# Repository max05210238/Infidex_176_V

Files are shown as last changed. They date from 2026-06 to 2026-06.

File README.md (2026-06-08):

# Infidex 176 V

Open source 3D printed panoramic 35mm film camera. Shoots a 3:1 panoramic frame (72 x 24 mm) on standard 35mm film using a Mamiya TLR taking lens.

Designed by **Denis Aminev** (Time to Waste). This repository is a community mirror created to preserve the project after the original site goes offline. See [Source and license](#source-and-license).

---

## Download

**Want everything in one file?** Download [`Infidex_176_V_complete.zip`](downloads/Infidex_176_V_complete.zip) (~20 MB) — this is the author's original release archive containing all STL, FBX, MOD files, the PDF manual, and the 3ds Max source. Just unzip and print.

You can also clone the full repo:

```bash
git clone https://github.com/max05210238/Infidex_176_V.git
```

Or use GitHub's **Code > Download ZIP** button above to grab the entire repository (docs included).

---

## What this is

Infidex 176 V is a fully working camera you print on an FFF/FDM printer and finish by hand. It is a plastic camera, so tolerances depend heavily on your printer, filament, and finishing. Expect to iterate. The designer printed all his cameras on a stock Ender 3 (Marlin firmware, Linear Advance) in cheap ABS.

| Spec | Value |
|---|---|
| Format | 3:1 panoramic, 72 x 24 mm |
| Film | 35mm (135) |
| Frames per 36-exp roll | 18 (19 if loaded in full dark, no leader waste) |
| Sprockets per frame | 16 (two standard 3:2 frames wide) |
| Taking lens | Mamiya TLR (C2/22/220, C3/33/330). 80mm recommended |
| Equivalent focal length | ~35mm on the 72mm-wide panoramic frame |
| Infinity focus (Mamiya 80mm) | ~31 m (~102 ft), helicoid fully screwed in |
| Focus throw | ~300 deg from infinity to 2 m |
| Body length | 168 mm |
| Body height (unibody) | 67 mm |
| Body thickness | 37.8 mm |
| Filament per camera | < 600 g (22 oz) |
| Tripod mount | 1/4" brass insert in base (8 x 8 mm) |

---

## Repository contents

```
Infidex_176_V/
├── Infidex 176 V manual.pdf         Original PDF manual by Denis Aminev
├── Infidex 176 V_NEWEST.max         3ds Max master CAD source file
├── STL/                              Print-ready STL parts
│   ├── Body/                           Body shells, unibody, doors (10 files)
│   ├── Lens mount/
│   │   ├── Focusing Helicoid/          Helicoid parts inc. Blue Dot variants (15 files)
│   │   ├── Classic Cone/               Fixed cone mount (3 files)
│   │   ├── Tube/                       Tube mount (3 files)
│   │   └── Old Version cone for T-22 lens/  Legacy T-22 cone (4 files)
│   └── Small parts/                    Knobs, gears, viewfinders, lens hoods, etc. (25 files)
├── FBX/                              FBX mesh exports (62 files)
├── MODS/                             Community modifications
│   ├── stl/                            Modified body, doors, helicoid mount (7 files)
│   └── fbx/                            FBX versions of the mods (7 files)
├── downloads/
│   └── Infidex_176_V_complete.zip    Author's original release archive (~20 MB)
├── docs/
│   ├── PRINTING.md                   Part catalog, print settings, dimensions
│   ├── ASSEMBLY.md                   Step-by-step build (14 steps)
│   ├── FOCUSING_AND_USAGE.md         Focus calibration, DOF table, shooting, scanning
│   └── VIDEO_TRANSCRIPT.md           Transcript of the designer's build video
├── NOTICE.md                         Attribution and redistribution notice
└── README.md                         This file
```

> If you regenerate STLs from `Infidex 176 V_NEWEST.max`, keep the part names above so the assembly docs stay valid.

---

## Required materials and tools

| Item | Notes |
|---|---|
| Mamiya TLR taking lens | C2/22/220 or C3/33/330. 80mm is the recommended focal length |
| Filament, 1 roll | Whole camera is under 600 g. ABS, PLA, or PETG all work (see notes below) |
| Superglue | Two-component with activator preferred. Standard CA works |
| Rigid wire, 0.6 to 0.8 mm | 20 to 30 cm. Stainless steel. Must spring well |
| Black flocked self-adhesive paper or matte black vinyl | Light-trap and anti-reflection surfaces |
| Black foam (dark gray minimum) | Light seals and film tension shims |
| Double sided tape | Not foam based |
| Wire nippers | |
| Calipers, metric | For dimension checks |
| Sandpaper, 100P to 800P | Grit depends on your filament |
| Spanner wrench | For the Mamiya lens mount nut |
| Scissors, tweezers | |
| Safety goggles + respirator | Mandatory for ABS fumes and superglue |

### Optional

35mm optical viewfinder, cutting knife with replaceable blades, 3D-print bed adhesive (spray), epoxy, plastic putty, 1000P fine sandpaper, textured bumper paint (e.g. Mipa), brass heat inserts (1/4" 8x8 mm and M3 4.5x6 mm), four or more M3x10 screws, soldering iron.

### Filament notes

ABS is the designer's choice: cheap, easy to shape by hand, good mechanical properties, but it shrinks, needs bed adhesive, slow speeds (30 to 70 mm/s), and an enclosed chamber. PLA works fine (tested by a friend of the designer). PETG can be too flexible in some parts. Composite filaments hide print lines well but are expensive and not every printer handles them.

---

## Print settings (designer's ABS profile)

| Setting | Value |
|---|---|
| Nozzle | 0.4 mm |
| Layer height | 0.2 mm |
| First layer height | 0.23 mm (glass bed) |
| Inner perimeters | 4 (important for rigidity) |
| Min top/bottom thickness | 2 mm |
| Infill | 25% max |
| Bed | 4 mm polished glass (PEI also fine) |

Print order does not matter, but print the **body first** to verify dimensions and tolerance before committing the rest. Reasonable deviation of 0.2 to 0.4 mm on printed parts is fine. See [docs/PRINTING.md](docs/PRINTING.md) for the full part catalog and per-part orientation.

---

## Build at a glance

Full walkthrough in [docs/ASSEMBLY.md](docs/ASSEMBLY.md).

1. Check body dimensions (37.8 mm thickness, 36.03 mm reference height).
2. Glue or screw the lens mount to the body. Install brass inserts if used.
3. Build the lens mount: lens board to inner thread, snap fixation ring, glue focus ring to the fixation ring (not the mount), verify the thread screws all the way in.
4. Install spool base, taking spool shaft, sprockets gear and sprocket shaft.
5. Bend the V-spring from wire, install it and the rewind knob.
6. Hinge the door with a ~63 mm wire pin. Line the pressure plate with black flock and add 4 to 5 mm foam tension strips.
7. Cold shoe, optional cable release port and lever knob, optional lens hood.
8. Calibrate the focus marks against ground glass (see [docs/FOCUSING_AND_USAGE.md](docs/FOCUSING_AND_USAGE.md)).

Wear eye and respiratory protection throughout. Glue fumes will make your eyes water.

---

## Lens mount options

Print only one set:

- **Focusing helicoid** (recommended, allows real focusing)
- **Classical cone** (fixed)
- **Tube mount** (fixed)

The lens cone from the previous IV model is compatible. All three are available with M3 screw holes.

**Blue Dot lens owners:** Blue Dot copies of the 80mm have a different flange distance and will not reach infinity with the standard helicoid. Print the shorter parts instead: `Helicoid_INNER_ring_80mm_shorter-2mm.STL` and `Helicoid_FOCUS_ring_ribs_shorter-2mm.STL`.

---

## Flocking paper templates

| Size | Location |
|---|---|
| 73 x 23 mm | Top and bottom of film chamber |
| 43 x 23 mm | Sides of film chamber |
| 82 x 33 mm | Pressure plate |

---

## Known limitations

- The frame counter requires **2 revolutions per shot** with the stock 8-tooth sprocket gear. A 16-tooth gear fixes this but lengthens the body.
- Long panoramic negatives are hard to scan at a normal lab. The designer scans on an Epson V850 Pro, or DSLR-scans and stitches two frames.

---

## Credits

Project by **Denis Aminev**, Time to Waste.

- **PaperBen** and **Giuseppe Spataro** for testing, advice, and inspiration. Giuseppe also solved the Blue Dot infinity issue.
- **ballanux** (YouTube) for helicoid system inspiration.
- **Oscar Oweson**, creator of the Oxygen panoramic camera (panomicron.com), for inspiration on some parts.
- **GLOwl** for the printable lens cap that inspired the kit version.
- **@analog_astronaut** for boosting the project.

---

## File sources

All design files in this repository originate from Denis Aminev's official releases on [timetowaste.ru](https://timetowaste.ru). The files were downloaded directly from the author's site before the scheduled shutdown.

| Path | Source | Notes |
|---|---|---|
| `Infidex 176 V manual.pdf` | Author's site, unchanged | The original PDF assembly and printing guide |
| `Infidex 176 V_NEWEST.max` | Author's site, unchanged | 3ds Max master CAD — regenerate STLs from this |
| `STL/` | Author's site, unchanged | Print-ready parts exported by the author |
| `FBX/` | Author's site, unchanged | Mesh exports for viewing/editing in other 3D tools |
| `MODS/` | Author's site, unchanged | Community-contributed body and door variants |
| `downloads/Infidex_176_V_complete.zip` | Author's original release archive | All binary files in one download (~20 MB) |
| `docs/` | Written for this mirror | English documentation reorganized from the PDF manual and the author's build video for easier web reading |

No design files have been modified. The documentation in `docs/` is a reorganization of the author's own content into Markdown for web readability.

---

## Source and license

Original project, files, and documentation by Denis Aminev (Time to Waste).

The designer's original site is shutting down. His own words:

> This website will disappear on 21 March 2027. Project brought to a point where I am satisfied with the results and I will no longer pay for this domain. Feel free to distribute files of the project on any other website or a platform. Thank you. Peace.

This repository exists to keep the project available after that date. All design credit stays with Denis Aminev. If you redistribute further, keep this attribution intact. See [NOTICE.md](NOTICE.md).

Original joint image gallery: https://timetowaste.ru/joint

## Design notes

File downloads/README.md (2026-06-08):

# Downloads

## Infidex_176_V_complete.zip (~20 MB)

The author's original release archive containing all project files in one download:

- All STL print files (organized by category)
- All FBX mesh exports
- Community modifications (MODS)
- Original PDF manual
- 3ds Max source file (.max)

This is the same set of files distributed across the repository, bundled for convenience. The archive was downloaded directly from [timetowaste.ru](https://timetowaste.ru) before the site's scheduled shutdown.

To download, click the file above then use the **Download raw file** button, or clone the repository.

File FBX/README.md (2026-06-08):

# FBX — Mesh Exports

61 files (mostly FBX, plus a few STL and DAE for metal parts). These are the author's mesh exports for viewing and editing in 3D applications other than 3ds Max.

The FBX files mirror the STL set but in a flat directory. For printing, use the STL files instead. The Kodak cone files (`Kodak_cone_base.*`, `Kodak_lens_board.*`) and metal part references (`METAL-Counter_gear.dae`, `METAL-Sprocket_gear.dae`, `METAL-Sprocket_shaft.dae`) are only available here.

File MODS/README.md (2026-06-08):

# MODS — Community Modifications

14 files (7 STL + 7 FBX) — community-contributed variants of the body, doors, and helicoid mount.

| Part | Description |
|---|---|
| `Body_top` / `Body_bottom` | Modified body shells |
| `Door_v1` through `Door_v4` | Four alternate door designs |
| `Helicoid_MOUNT_BASE` | Modified helicoid mount base |

Both STL (for printing) and FBX (for editing) versions are provided in their respective subfolders.

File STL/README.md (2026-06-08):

# STL — Print-Ready Parts

57 STL files organized by function. All files are the author's original exports from `Infidex 176 V_NEWEST.max`.

## Folders

| Folder | Contents |
|---|---|
| `Body/` | Body shells (top/bottom, unibody, ver2 variants) and four door options |
| `Lens mount/Focusing Helicoid/` | Recommended mount — allows real focusing. Includes Blue Dot shorter variants |
| `Lens mount/Classic Cone/` | Fixed-focus cone mount |
| `Lens mount/Tube/` | Fixed-focus tube mount |
| `Lens mount/Old Version cone for T-22 lens/` | Legacy cone for Lomo T-22 lens (from earlier model) |
| `Small parts/` | Knobs, gears, viewfinders, lens hoods, lens cap, cold shoe, pressure plate, etc. |

Print only **one** body set (top+bottom or unibody), **one** lens mount type, and **one** door variant. See [docs/PRINTING.md](../docs/PRINTING.md) for settings and orientation.

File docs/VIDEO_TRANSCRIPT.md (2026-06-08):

# Build Video Transcript

Transcript of Denis Aminev's Infidex IV-to-V build video, organized by chapter with timestamps. Lightly cleaned for readability; the designer narrated it as improvised live commentary. Read the PDF manual for everything not covered here.

---

## 1. Intro (0:21)

Assembling the new Infidex V camera. This one is full improvisation, not scripted like the earlier videos. Plan: disassemble an Infidex IV and reuse its optical viewfinder and Mamiya 80mm lens.

## 2. Materials and tools (1:06)

Walks through the essential materials and tools laid out, plus a second table of "non-essential" items. Foam is essential. Open the assembly guide first. Calipers, mislabeled as not essential, are needed.

## 3. Checking dimensions (1:34)

- Whole camera thickness should be 37.8 mm, measured mid-side. Measured: 37.51 mm. Acceptable for FFF/FDM.
- Model height should be 36.03 mm. Measured: ~36 mm. Good to proceed.

## 4. Body assembly (2:17)

Check part fitment. A small gap between halves is fine. Chisel off bumps and flatten with sandpaper, scraping carefully (sharp edges). Check the smaller parts fit too; remove a few bumps where needed.

The taking spool shaft (step 6 in the manual) goes in at an angle first, then upright, then pushed up. Place the shaft holder inside before gluing. File any stiffness until smooth.

There is a pocket at the top right for a gear; it should sit and rotate freely. The sprocket shaft is placed from the top and located in its slot.

Before gluing, place the printed pressure plate on its position as a guide. It moves freely, that is fine. It ensures the two film rails stay flat and parallel while the body halves are glued, which is critical. Do not rush. Press the glued halves together for a few seconds.

A small bump indicates the bottom side of the helicoid mount.

## 5. Helicoid assembly (5:54)

Prepare surfaces and check fit. The thread should screw in and out freely. Snap the fixation ring into its groove so it rotates freely.

Glue the focus ring to the snapped fixation ring, not to the mount, body, or your fingers. Do not apply glue to the focus ring itself, or pushing it on will bond it to the helicoid mount. Apply a decent but mild amount of superglue to the fixation ring.

The mount has two slide guides for the inner-ring rails. Engage them, then rotate clockwise to thread it in.

Only the thread holds the assembly together, so be careful when focusing close. The camera can do mild macro, but unscrewing too far drops the lens out.

Glue the inner thread to the lens board, aligning the matching marks on both parts. Press mildly.

## 6. Door installation (9:12)

The door will not fit at first. Remove material from the hinge points and edges. The lower ledge was printed with supports and ends up slightly thick, so remove a little material until the door fits.

## 7. Brass thread inserts (10:14)

The soldering iron is hot, be careful. Apply heat slowly to seat the inserts. One M3 insert done. The larger 1/4" thread hole is easier to seat than the small M3 ones.

## 8. Spring and hinge wires (11:13)

The hinge uses rigid stainless wire, about 0.62 mm, that goes straight in.

The spring seats inside the body and acts as a stopper for the rewind knob. Form it by making one coil around something thin (an M3 screw, or better a plain nail). Push the coil into place with a file. When seated correctly, pulling the knob shows the spring working as a stopper. This part is hard. ("I cried only three times.")

The winding knob and counter go on after the paint job.

## 9. Pressure plate (12:54)

Line the pressure plate with black flocked paper. It must be black, not light gray or white, or images get halation everywhere. Cut to size and glue on. Matte black vinyl also works; do not use glossy. Apply self-adhesive flocking inside the chamber too. This is easier before the body halves are glued. The cold shoe was installed off-camera.

## 10. Lens installation (13:56)

When transferring the long thread from the disassembled Infidex IV, it may not fit at first; work it until it seats.

## 11. Marking distances on the helicoid (14:44)

Focus on a target at a known distance and mark the helicoid.

- 2 m mark made by focusing on a target exactly 2 m away.
- Then 5 m, 10 m, 15 m, 20 m, and 31 m to infinity.

Camera is then painted and fully functional.

## 12. A little talk (15:52)

There was a small light leak in the lens board. It was found and fixed in the STL files (link in the original video description). Read the assembly guide first; a lot is not covered in the video.

## 13 to 15. Test shots and outro (16:11)

Test images shown. Thanks to viewers. Plus a t-shirt a friend gifted.

---

Original channel and site: Time to Waste (timetowaste.ru). Project by Denis Aminev.

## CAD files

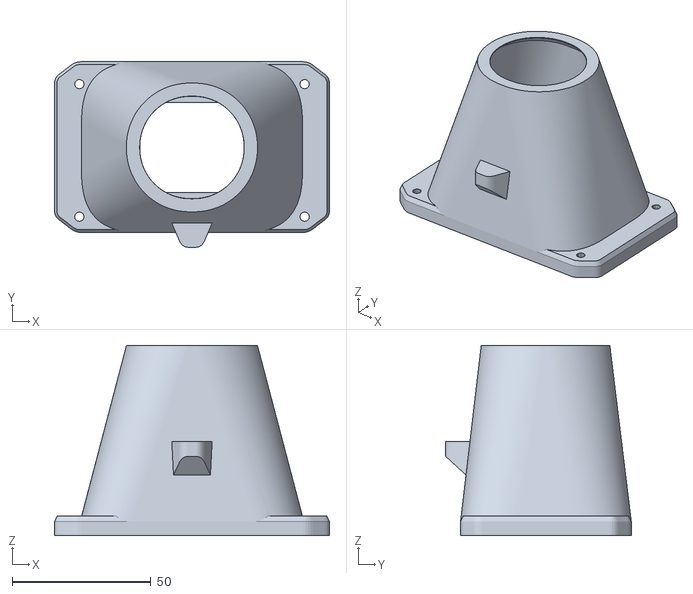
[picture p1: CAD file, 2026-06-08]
FBX/Kodak_cone_base.stl
99.3 x 67.0 x 68.7

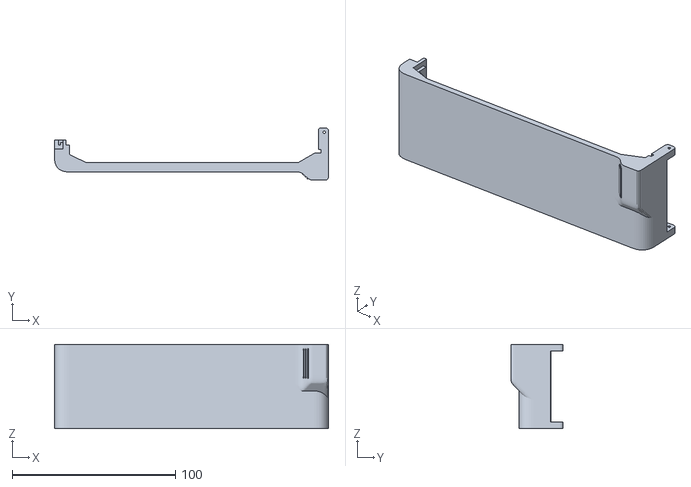
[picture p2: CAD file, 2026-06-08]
STL/Body/Door_var2.stl
168.0 x 32.1 x 51.7

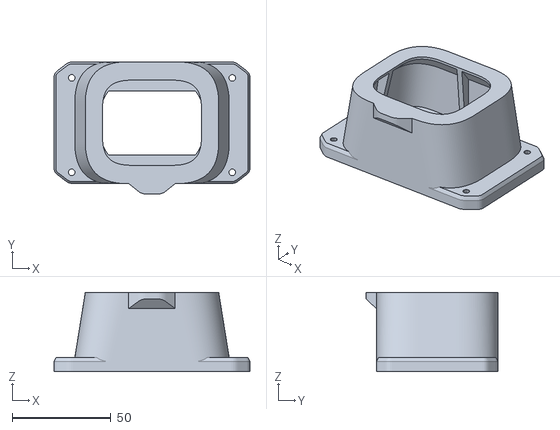
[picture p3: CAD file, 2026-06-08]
STL/Lens mount/Classic Cone/CONE_lens_classic_BASE_ver2.stl
99.3 x 67.0 x 40.2

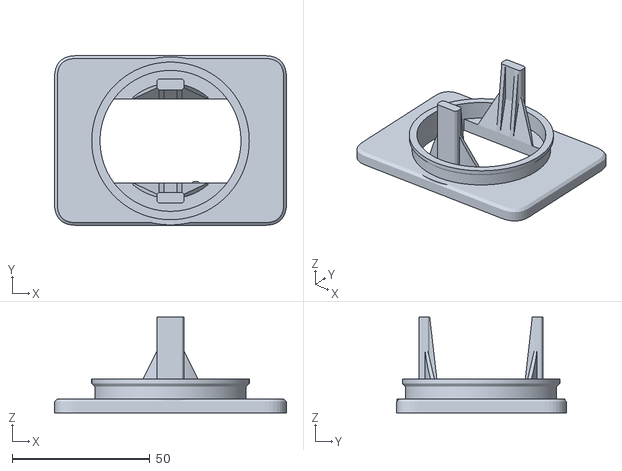
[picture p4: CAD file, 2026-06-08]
STL/Lens mount/Focusing Helicoid/Helicoid_MOUNT.stl
84.3 x 61.7 x 34.7

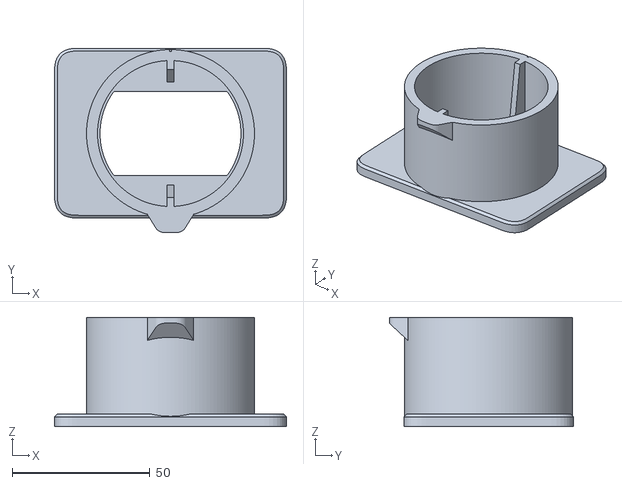
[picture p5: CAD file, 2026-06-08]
STL/Lens mount/Tube/Tube_lens_mount.stl
84.3 x 67.0 x 39.7

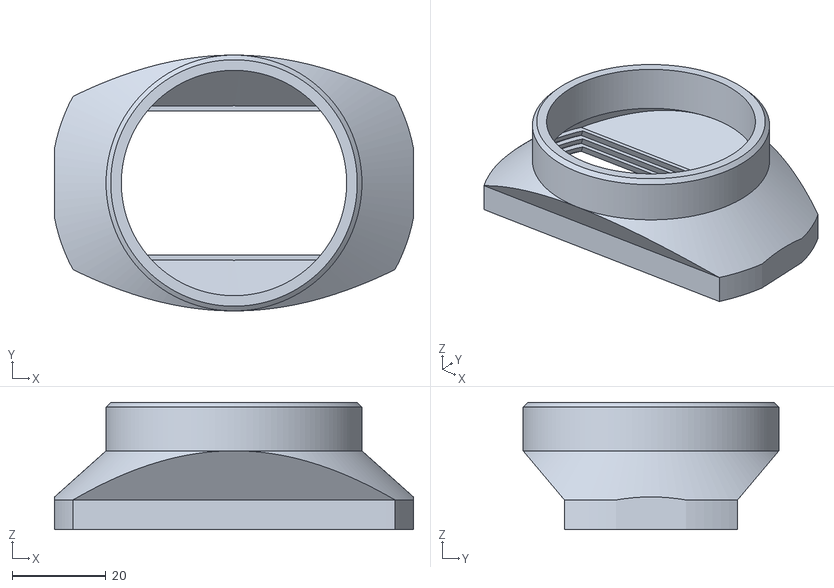
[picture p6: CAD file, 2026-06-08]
STL/Small parts/Lens_Hood_Mamiya_Sekor_55mm.stl
76.5 x 54.5 x 27.2

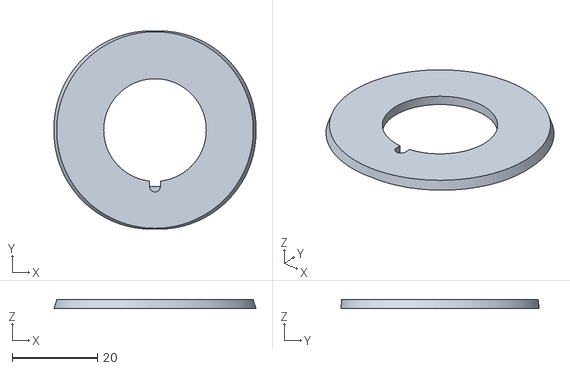
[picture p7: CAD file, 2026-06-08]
FBX/Kodak_lens_board.stl
47.3 x 46.4 x 2.00

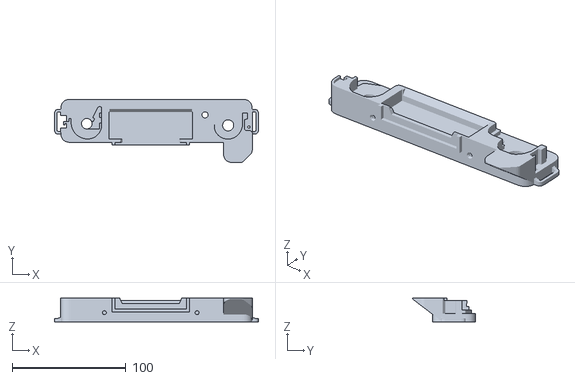
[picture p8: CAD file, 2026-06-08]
MODS/stl/Body_top.stl
179.0 x 55.6 x 21.0

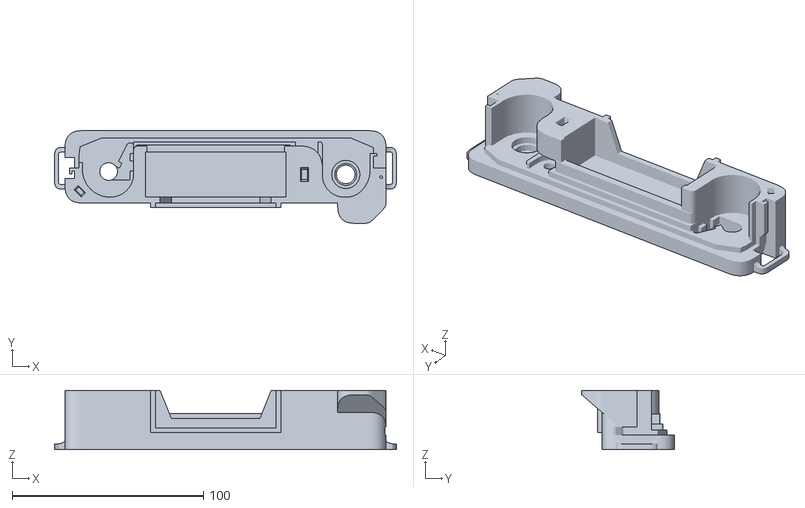
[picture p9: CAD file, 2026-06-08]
STL/Body/BODY_top.stl
179.0 x 48.5 x 31.0

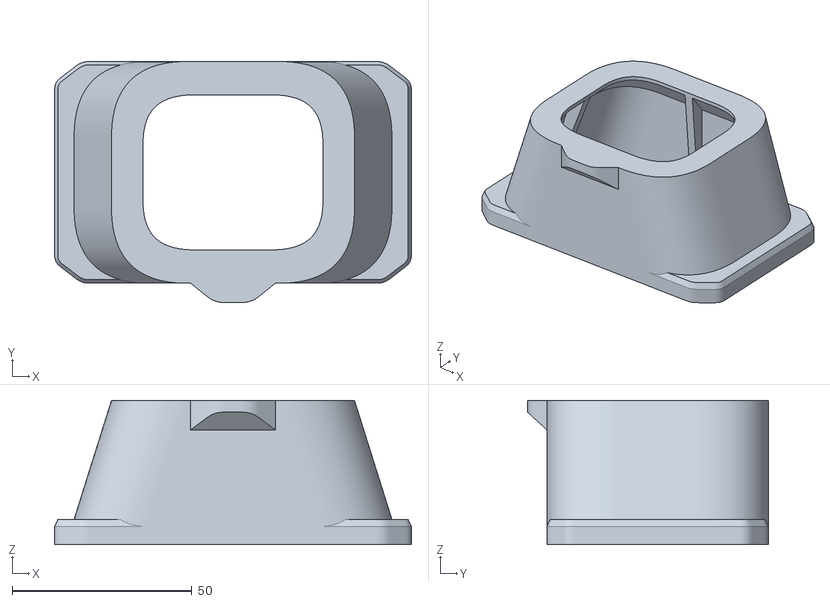
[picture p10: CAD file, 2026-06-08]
STL/Lens mount/Classic Cone/CONE_lens_classic_BASE.stl
99.3 x 67.0 x 40.2

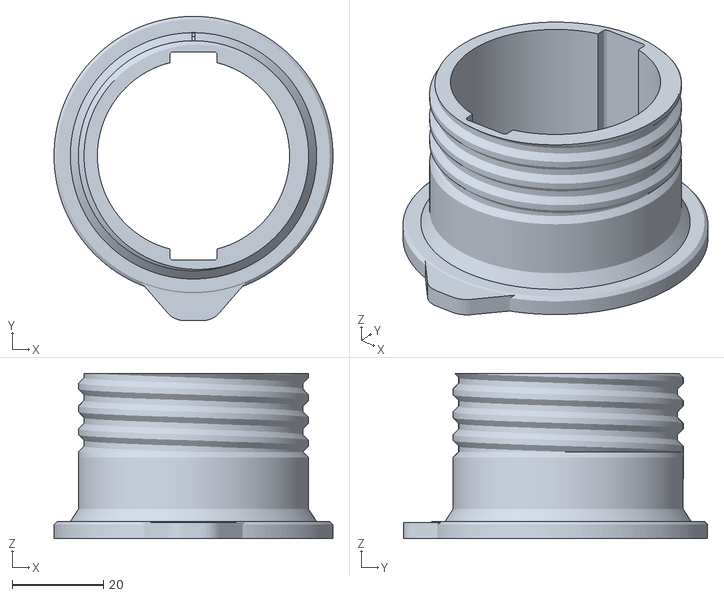
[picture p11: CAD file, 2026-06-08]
STL/Lens mount/Focusing Helicoid/Helicoid_INNER_ring_for_80mm_lens.stl
61.0 x 66.5 x 36.1

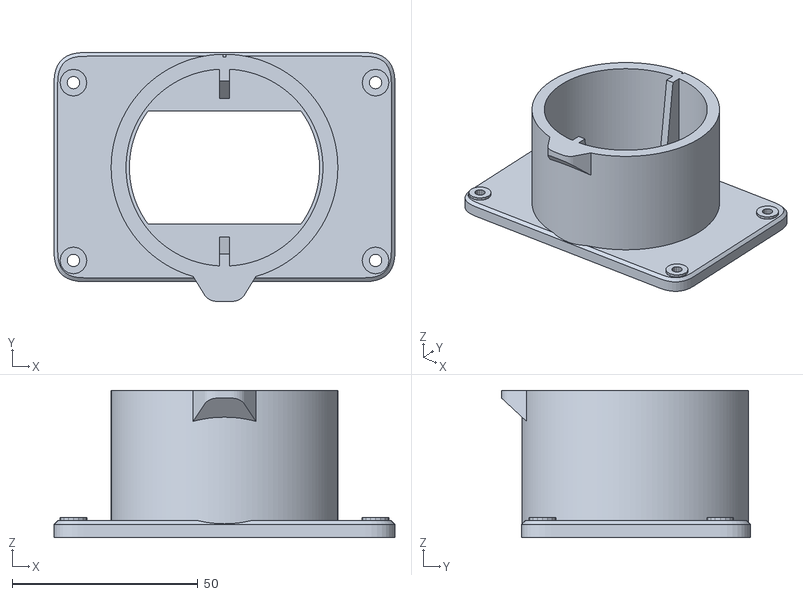
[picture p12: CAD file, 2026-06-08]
STL/Lens mount/Tube/TUBE_lens_mount_ver2.stl
91.8 x 67.0 x 39.7

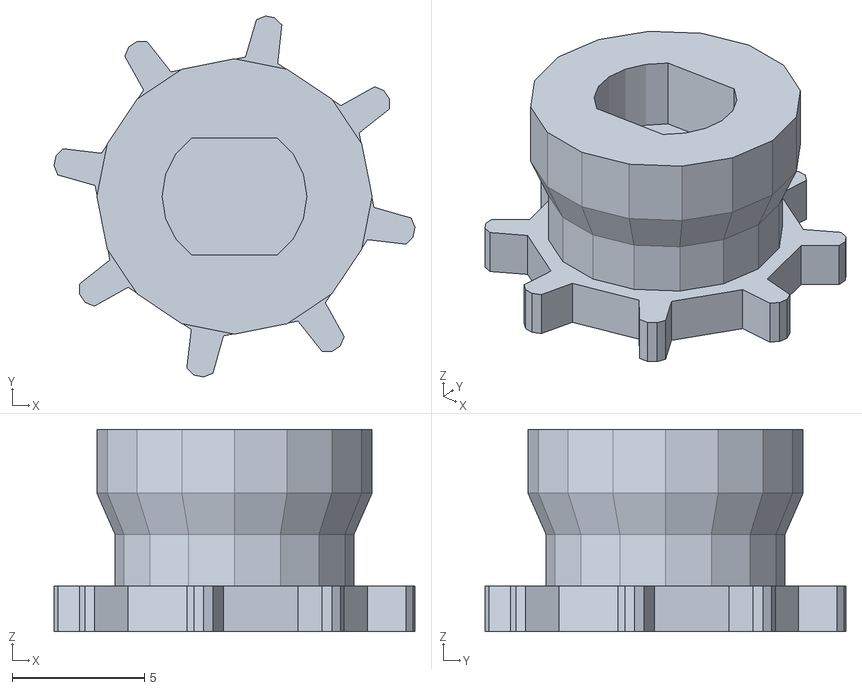
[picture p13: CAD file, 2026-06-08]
STL/Small parts/Sprocket_gear.stl
13.6 x 13.6 x 7.63

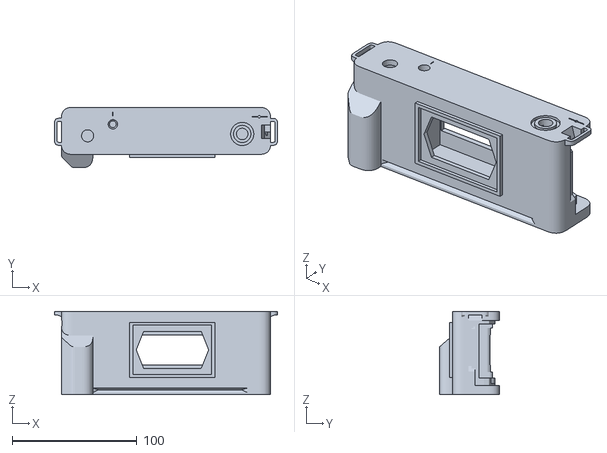
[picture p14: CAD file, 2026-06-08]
STL/Body/BODY_UNIBODY.stl
179.0 x 48.5 x 67.0

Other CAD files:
STL/Lens mount/Classic Cone/CONE_lens_classic_BOARD.stl
STL/Lens mount/Focusing Helicoid/Helicoid_FOCUS_ring_ribs_shorter-2mm.stl
STL/Lens mount/Tube/Tube_Lens_BOARD.stl
STL/Small parts/Rewinding_knob_var2.stl
MODS/stl/Body_bottom.stl
MODS/stl/Door_v1.stl
MODS/stl/Door_v2.stl
MODS/stl/Door_v3.stl
MODS/stl/Door_v4.stl
MODS/stl/Helicoid_MOUNT_BASE.stl
STL/Body/BODY_UNIBODY_ver2.stl
STL/Body/BODY_bottom.stl
STL/Body/BODY_bottom_ver2.stl
STL/Body/BODY_top_ver2.stl
STL/Body/Door_var1.stl
STL/Body/Door_var3.stl
STL/Body/Door_var4.stl
STL/Lens mount/Focusing Helicoid/Helicoid_FIX_ring.stl
STL/Lens mount/Focusing Helicoid/Helicoid_FOCUS_ring_NO_ribs.stl
STL/Lens mount/Focusing Helicoid/Helicoid_FOCUS_ring_NO_ribs_shorter-2mm.stl
STL/Lens mount/Focusing Helicoid/Helicoid_FOCUS_ring_ribs.stl
STL/Lens mount/Focusing Helicoid/Helicoid_INNER_ring_55mm (+0.5mm).stl
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

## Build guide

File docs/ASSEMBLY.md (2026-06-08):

# Assembly Guide

Fourteen steps from printed parts to a shooting camera. Source: Infidex 176 V manual by Denis Aminev.

**Safety:** wear safety glasses and a respirator. Glue fumes are dangerous and will make your eyes water. Do not point a cutting knife toward yourself. Work without rushing.

## Before you glue anything

Check the fit of large parts first.

- Too loose: reprint.
- Too tight: shape with a file or sandpaper.
- Rotating parts should neither stick nor wobble.
- Exception: the taking spool shaft is meant to seat slightly deeper into its hole at the bottom of the body.

## Body

Unibody builders skip to the lens mount.

For two-piece bodies, a gap up to 0.4 mm between halves is acceptable. Sand the mating faces, clamp, and apply pressure while gluing. Fill the seam with putty or solder it.

**Critical:** keep the two frame planes as parallel as possible, because they define the focus plane. Place both halves on a flat surface, or use the film pressure plate sitting on the film rails as a guide while the glue sets.

If your body has brass-insert holes, install the inserts now with a soldering iron (M3 4.5x6 mm in front, 1/4" 8x8 mm in the base). Trim squeezed-out plastic flush.

## Lens mount

After the body is glued, dry-fit the lens mount into the ledge on the body. Grind material off the mount if needed.

**Step 1.** Glue the lens mount to the body with superglue or epoxy, or attach it temporarily with M3x10 screws. A small raised box on the part marks the bottom side. Apply glue to the indicated face, not the box.

> Tube mount and classical cone install the same way.

**Step 2.** Glue the lens board to the inner thread ring. Align the two highlighted marks so they sit on one line. Use the lower lens board only if the focal length is too long for infinity focus.

**Step 3.** Snap the fixation ring into the lens mount groove.

**Step 4.** Apply glue to the face of the fixation ring you just snapped in. **Do not glue it to the mount groove.** Place the focus ring on the fixation ring and press mildly for a few seconds. Do not put glue directly on the focus ring, or you risk bonding it to the mount. The focus ring must rotate freely without wobbling and without falling out of the groove.

**Step 5.** Fit the inner thread (with lens board) inside the focus ring so the mount slides drop into the inner-ring grooves. Rotate the focus ring clockwise. It should screw all the way in. If it binds, print a smaller inner thread or sand the surface. If greasing, use thick grease, not liquid. Unscrew it again afterward so it does not block the next steps.

## Film transport

**Step 6.** Place the spool base on the top side of the body. Apply glue to the marked area of the taking spool shaft, then use tweezers to insert it at a slight angle, push down and forward until it stops, and glue the two parts. It must still move freely up and down for now. Glue the winding knob on top later, after body and paint work.

**Step 7.** Drop the sprockets gear into its slot, then apply glue to the sprocket shaft and attach it to the gear through the shaft hole from above.

After painting, glue the frame counter cap to the sprocket shaft. Mask these top parts before painting, or fit them after paint.

## Rewind spring and door

**Step 8.** Bend the wire into a V-shaped spring with a small coil so it is stiff enough to hold the rewind knob. Measure and cut to length.

**Step 9.** Seat the spring inside its slot. There are three bumps that locate it. Insert the rewind knob and confirm it locks in both open and closed positions. Pull it back out afterward so it does not interfere with assembly and painting. This step is fiddly. Be patient.

**Step 10.** Place the door and check its fit. A slightly tight door is fine. With the door closed, hinge it by pushing the wire pin through the hole in the body below. Wire length is about 63 mm. It must fit tightly and not fall out in use. The hole can be soldered or puttied for security.

Cover the flat side of the pressure plate with black flocked paper or matte black vinyl. Do not use gray or lighter material, or you get halation and haze on images.

**Step 11.** Cut two foam strips, apply double-sided tape to both sides, and stick them to the pressure plate between the ribs. 4 to 5 mm thickness is enough.

Set the pressure plate flat inside the body where the film sits, so it covers the frame window without touching anything. Apply double-sided tape and close the door fully so the plate transfers onto the door. Open the door, press the plate against it a couple of times to seat it. Fit the latch and confirm the door sits flush with the body.

Attach the Mamiya lens to the inner thread ring using the original mount nut from the Mamiya TLR lens board.

## Finishing parts

**Step 12.** Mount a cold shoe (kit part or third-party) at your preferred spot.

**Step 13.** Mamiya TLR lenses lack a cable release port. Install the printed cable release port and lever knob. Print these at 0.1 to 0.12 mm layer height.

**Step 14.** Optionally print a lens hood (two variants, friction fit on the front element). Check your lens diameter and scale the hood to match.

Next: calibrate focus marks in [FOCUSING_AND_USAGE.md](FOCUSING_AND_USAGE.md).

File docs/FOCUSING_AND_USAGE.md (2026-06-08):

# Focusing, Depth of Field, and Usage

Source: Infidex 176 V manual by Denis Aminev.

## Setting focus marks

You need ground glass to calibrate. The designer uses 1 mm microscope slide glass (75 x 25 mm) frosted on one side with glass matting paste.

1. Screw the helicoid fully in. On the Mamiya 80mm this is infinity, about **31 m (~102 ft)**.
2. Wrap a paper strip around the focus ring.
3. One **300 degree** turn covers infinity down to **2 m**. You can go closer into macro, but the lens can fully unscrew and fall out, so be careful.
4. Confirm infinity by focusing on something far away (a mountain, tower, or tall building) through the ground glass.
5. For near distances, place a bright, contrasty target at each distance (20, 15, 10, 5 m, and so on), focus via ground glass, and mark the strip.
6. Scan the finished strip and print your own focus scale.

A sample 300-degree strip is **170 mm** long. Typical marks: infinity, 20, 15, 10, 5, 2 m. Treat the sample as a guide, not an exact ruler. Calibrate to your own build.

## Depth of field table (Mamiya 80mm TLR, metric)

Each cell is the near-to-far in-focus range at the given focus distance and aperture.

| Aperture | inf. | 9 m | 4.5 m | 3 m | 2 m |
|---|---|---|---|---|---|
| f/2.8 | 32 m to inf. | 7 to 12 m | 4 to 5.5 m | 2.8 to 3.4 m | 2 to 2.2 m |
| f/4 | 22 m to inf. | 6.5 to 15 m | 3.8 to 5.7 m | 2.6 to 3.5 m | 1.9 to 2.3 m |
| f/5.6 | 15 m to inf. | 6 to 21 m | 3.5 to 6.3 m | 2.5 to 3.7 m | 1.8 to 2.4 m |
| f/8 | 10 m to inf. | 5 to 51 m | 3.2 to 7.6 m | 2.4 to 4 m | 1.8 to 2.6 m |
| f/11 | 8 m to inf. | 4.3 m to inf. | 3 to 10 m | 2.2 to 4.7 m | 1.7 to 2.8 m |
| f/16 | 5.5 m to inf. | 3.5 m to inf. | 2.5 to 23 m | 2 to 6.4 m | 1.5 to 3.2 m |
| f/22 | 4 m to inf. | 2.8 m to inf. | 2 m to inf. | 1.8 to 10 m | 1.4 to 4 m |
| f/32 | 2.7 m to inf. | 2 m to inf. | 1.8 m to inf. | 1.5 m to inf. | 1.2 to 7.3 m |

Sharpest apertures sit in the middle of the range. f/16, f/22, and f/32 enter the diffraction zone. The table starts at 2 m because that matches how the designer uses the camera.

## First tests

You already verified infinity focus and helicoid travel during assembly. Next, test film transport.

Use a roll of already-developed, cheap, or expired 35mm film so a jam costs nothing. Simulate normal advance and rewind.

- **Crunching sound and torn sprocket holes:** the 8-tooth sprocket gear is too sharp and square. File it to a smoother profile. You can copy the tooth shape from another film camera.
- **Film slipping past gear teeth:** glue a piece of foam on the door near where the film contacts the sprocket gears to add tension.

## Shooting

- Format is 3:1, **72 x 24 mm**. One frame equals two standard 3:2 frames, exactly **16 sprockets**.
- A 36-exposure roll yields **18 frames** (19 if loaded in total darkness without wasting the leader, though the film may not lie as flat).
- Make sure the counter start mark is at the start position before shooting.
- Respooled films can hold fewer than 36 exposures.

**Frame counter quirk:** with the stock 8-tooth sprocket, you advance **2 revolutions of the frame counter per shot**. Swapping in a 16-tooth gear fixes this but lengthens the body, which the designer avoided.

## Viewfinder

The kit viewfinder (two variations) works by aligning both frame outlines into a single silhouette while looking through. It is reasonably accurate; keep headroom top and bottom. Alternatively use a 35mm optical viewfinder and mark its new framing using ground glass.

## Scanning

Long panoramic negatives are awkward for most labs. Options:

- **Flatbed:** Epson V850 Pro. Easiest, not the highest quality.
- **DSLR scanning:** photograph and stitch two frames. More work, better results.

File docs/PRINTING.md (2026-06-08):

# Printing Guide

This document catalogs every printable part, the variations available, recommended orientation, and the dimensional checks you must pass before assembly.

> Source: Infidex 176 V manual by Denis Aminev. Part names match the STL files in `STL/`.

## Print settings (ABS reference profile)

| Setting | Value |
|---|---|
| Nozzle | 0.4 mm |
| Layer height | 0.2 mm |
| First layer height | 0.23 mm (glass bed) |
| Inner perimeters | 4 |
| Min top/bottom thickness | 2 mm |
| Infill | 25% max |
| Bed | 4 mm polished glass, or PEI |

Print order is free, but print the body first to confirm fit. Some small parts benefit from rafts, brims, or mouse ears for first-layer adhesion.

## Dimension checks

Verify after printing the bottom body part. Deviation of 0.2 to 0.4 mm on a printed part is acceptable (not in the slicer, only on the physical part).

| Dimension | Target |
|---|---|
| Body thickness (measured mid-side) | 37.8 mm |
| Model height | 36.03 mm |
| Full body height (unibody) | 67 mm |
| Body length | 168 mm |
| Knob shoulder width | 25.3 mm |
| Inner span | 124 mm |
| Vertical reference | 47.5 mm |
| Rewind knob diameter | ~25 mm |
| Lens barrel reference diameter | ~60 mm |

## Body

Print one of four variants. All use supports in "from bed" mode (tree supports recommended).

| Variant | Files | Notes |
|---|---|---|
| 1 (two-piece) | `BODY_bottom_var1`, `BODY_top_var1` | Standard split body |
| 2 (two-piece) | `BODY_bottom_var2`, `BODY_top_var2` | Adds front M3 brass-insert holes for screwing the helicoid mount |
| 3 (unibody) | `BODY_unibody_var1` | Single piece. "Top to down" orientation may print better (untested) |
| 4 (unibody) | `BODY_unibody_var2` | Single piece with front M3 brass-insert holes |

Two-piece bodies need the seam filled with putty or soldered, and the frame planes kept parallel during gluing (this sets the focus plane).

## Lens mount (choose one)

### Focusing helicoid (recommended)

| Part | Files | Notes |
|---|---|---|
| Mount | `Helicoid_MOUNT_ver1` | Glued to body |
| Mount, screwable | `Helicoid_MOUNT_ver2` | Four holes for M3x10 screws to the body |
| Focus ring | `Helicoid_FOCUS_ring_ribs` | Ribbed grip |
| Focus ring, smooth | `Helicoid_FOCUS_ring_NO_ribs` | Same ring, no ribs |
| Inner ring | `Helicoid_INNER_ring` | Threaded inner barrel |
| Fixation ring | `Helicoid_FIX_ring` | Snaps into the mount groove |
| Lens board | `Helicoid_Lense_BOARD` | Start with this one |
| Lens board, lower | `Helicoid_Lense_BOARD_lower` | Use only if focal length is too long for infinity |

**Blue Dot lens (shorter flange distance):**

| Part | File |
|---|---|
| Inner ring, 2 mm shorter | `Helicoid_INNER_ring_80mm_shorter-2mm` |
| Focus ring, 2 mm shorter | `Helicoid_FOCUS_ring_ribs_shorter-2mm` (or the no-rib equivalent) |

### Classical cone

| Part | Files | Notes |
|---|---|---|
| Cone base | `CONE_lens_classic_BASE` | Also available with M3 holes |
| Lens board | `CONE_lens_classic_BOARD` | |

### Tube mount

| Part | Files |
|---|---|
| Tube mount | `Tube_lens_mount` |
| Lens board | `Tube_Lense_BOARD` |

## Door

Four versions: door with or without film reminder and thumbrest, in different combinations. Print in "from bed" mode with supports. Use rafts or brims if needed.

Orient the door as shown in the manual so it is rigid in both horizontal axes. Printing flat on the door face leaves it too weak to hold closed.

**Note:** the lower ledge sags slightly because of the supports, so remove a little material to fit it into the door frame.

## Small parts

Print these heavy-loaded parts **separately** for strong interlayer adhesion, since combined prints can come out too weak:

- Rewind knob
- Taking spool shaft
- Latch

Other small parts can be printed in one set, and printing them at twice the quantity is sensible because some get damaged during fitting. Small parts that are available in **two variations**: winding knob, rewinding knob, viewfinder.

Functional small parts (exact filenames in `STL/`):

- Spool base
- Taking spool shaft
- Sprockets gear (8-tooth stock) and sprocket shaft
- Frame counter and frame counter cap
- Winding knob (2 variants)
- Rewinding knob (2 variants)
- Latch
- Cold shoe (kit part, or use a third-party shoe)
- Cable release port and lever knob (print at 0.1 to 0.12 mm layer height)
- Viewfinder (2 variants)
- Pressure plate
- Lens hood (2 variants, friction fit, scale to your lens diameter)

## Brass inserts

If you chose a body variant with insert holes:

| Insert | Diameter | Height | Location |
|---|---|---|---|
| M3 | 4.5 mm | 6 mm | Front, for helicoid mount |
| 1/4" | 8 mm | 8 mm | Base, for tripod |

Install with a soldering iron. Remove squeezed-out plastic flush with the body surface afterward.

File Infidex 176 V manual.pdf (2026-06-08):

## INTRODUCTION

Infidex 176 - is the open source project of 3D printed panoramic film camera. The project is designed to be printed on an FFF printer, so if you plan to print using a different technology, I cannot guarantee the same result.

It is important to understand that this is a completely ready-to-use project, but it still provides plenty of s p a c e for your needs and creativity.

And it is even more important to remember that this is a plastic camera. What imposes some restrictions. Plus, let's not forget that your printer, the chosen plastic, finishing materials and the number of stones in your neighbor's garden play a huge role (about 80 percent). By this I mean that it may take more than one attempt to turn a roll of plastic into a working camera. But I ask you not to dwell on failures, but to analyze and overcome problems.

I printed all my cameras on a stock Ender 3 with Marlin firmware and Linear Advance enabled using cheap ABS plastic. So I can't guarantee that all the tolerances and scales will work for your setup. Experiment.

## MATERIALS

## List of necessary materials and tools

- Mamiya TLR system taking lens (C2(Mamiyaflex)/22/220, C3/33/330)
- 1 roll of filament (whole camera takes less than 600 grams - 22 ounces)
- Superglue (preferably two-component with an activator, but I used regular one)
- Rigid wire with a diameter of 0,6-0,8mm (20-30cm will be enough. I used stainless steel wire. It should spring well - this is important)
- Black velvet self-adhesive paper (flocked paper) or vinyl self-adhesive film
- Black foam (at least dark gray)
- Double sided tape (not foam based)
- Pair of nippers for wire
- Calipers with metric system
- Sandpaper (depends on the material you are printing with, take from 100P up to 800P)
- Spanner wrench
- Scissors
- Tweezers
- Protective goggles and respirator

## List of optional materials and tools

- 35mm optical viewfinder
- Cutting knife (with changeable blades is fine)
- 3d printing adhesive glue (i used in spray format and can recommend to use it for you too)
- Epoxy glue
- Putty for plastic
- Light grain sandpaper (1000P)
- Texture car bumper paint (“Mipa” for example)
- Brass heat inserts with ¼” thread 8mm x 8mm
- Brass heat inserts with M3 thread 4,5mm x 6mm (and at least four M3*10 screws)
- Soldering iron

## Lens

As you can probably guess at this point, project requires the taking lens from Mamiya TLR system. This system has different focal lengths (65mm, 80mm, 105mm, 130mm etc). In my opinion 80mm works the best. It provides 35mm equivalent focal length on 72mm panoramic frame (in width). Which allows you to use 35mm optical viewfinder. Also it’s really easy to find and buy even with a whole Mamiya camera and you don’t need to mess up it since the lenses on this system are interchangeable. Lens is holded by a thread nut which you need to hold lens on the infidex camera. Unfortunately you need to desolder a synchro contact wire. About Lomo T-22 lens: you still can attach it but only with the cone from previous IV version of infidex. Files are included

## Filament

I prefer printing all my cameras using ABS for specific reasons: it is easy to shape with hand tools and believe me, there will be a lot of shaping; it is cheap; it has good mechanical properties for use in various environments. However, the material is quite finicky and shrinks during printing and cooling; requires adhesive glue; slow speeds (from 30mm/s to 70mm/s max); enclosed chamber and full cooling down awaiting till you can pick up parts, unless they're gonna delaminate.

My friend printed a few cameras out of PLA and they work absolutely fine. PETG can be too flexible in some parts. Composite filaments good at hiding printing imperfections, looks great and in theory they should be perfect for this role, but not every printer can handle composites, plus they are really expensive.

Other materials and tools will be described as you progress through the instructions.

## Precautionary measures:

Please wear respiratory and eye protection when handling toxic plastics such as ABS and when working with superglue. When working with a cutter knife, do not point the tip of the blade in your direction. Work carefully, without rushing.

## PRINTING

## Choosing parts for your camera

The fifth version of the camera offers some choice of parts for greater ease of use and modifications. Read the manual to the end to see all the options available for printing.

The order in which the parts are printed does not matter. However, I recommend printing the body first to check the measurements and tolerance, if necessary you can later scale the parts and reprint them. Some reasonable uncertainty in measurements is possible.

## Common printer settings

Here is list of my settings which i used to print all my cameras with ABS plastic:

Nozzle | 0,4mm
Layer height | 0,2mm
First layer height | 0,23mm (depends on your bed. Mine is glass)
Number of inner perimetrs | 4 (an important parameter ensuring rigidity)
Minimal thickness of top and bottom layers | 2mm
Infill | 25% max (shape on your taste)
Bed surface | 4mm glass (normal polished glass) Of course PEI and other works fine

## BODY

VARIATION 1
Contain two parts: BODY_bottom_var1 and BODY_top_var1

Supports - Yes, “from bed” mode. I used “tree” supports on every part

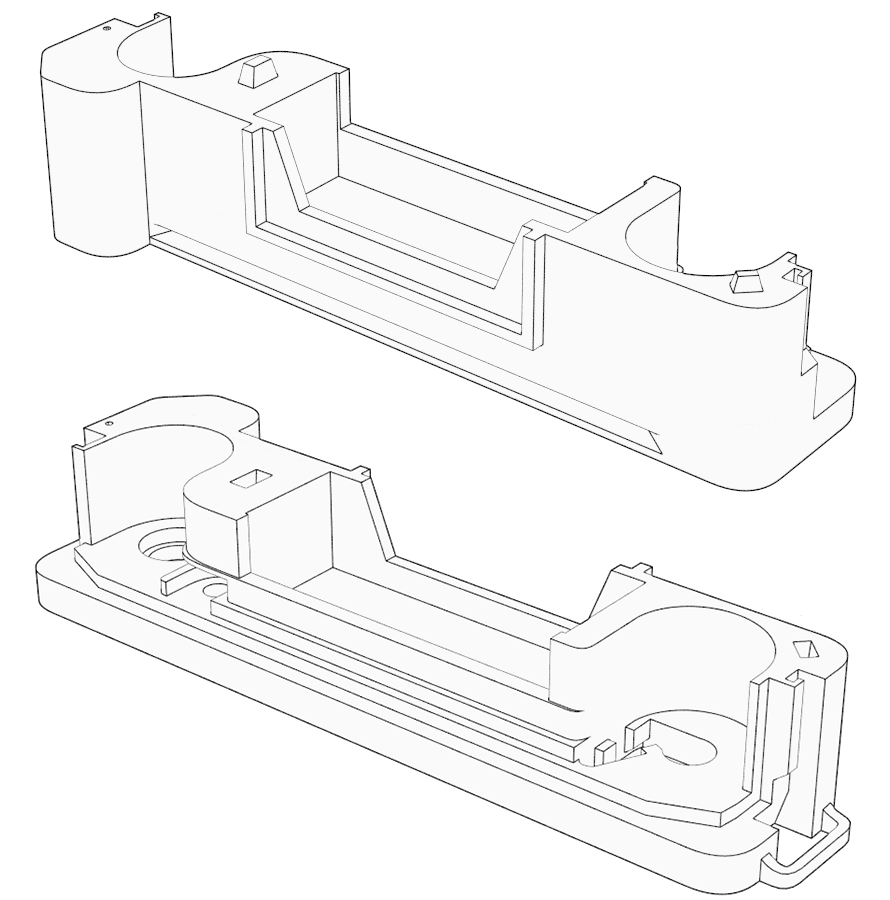
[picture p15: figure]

placement on printer bed

VARIATION 2
Contains same two parts BODY_bottom_var2 and BODY_top_var2 with additional holes in front for M3 brass inserts for only mounting helicoid. Same placement.

Supports - Yes, “from bed” mode

VARIATION 3 - “Unibody”
Contains one model BODY_unibody_var1

Supports - Yes

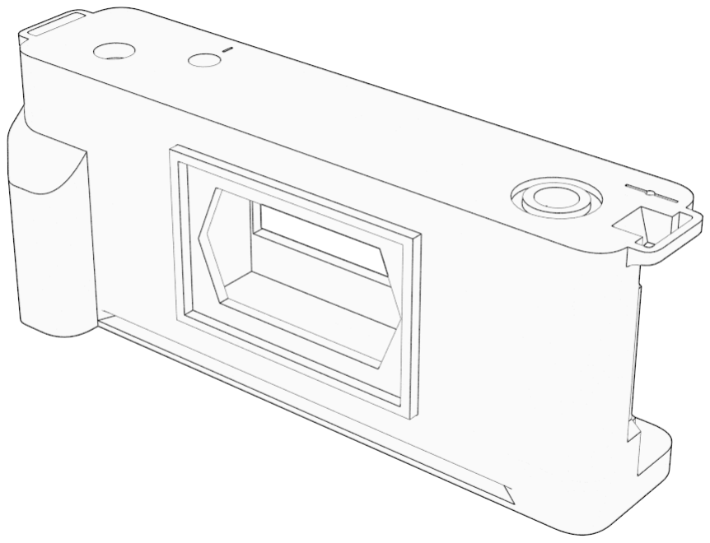
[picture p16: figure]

probably placement on “top to down“ should be better (need tests)

VARIATION 4 - “Unibody”
Contains one model BODY_unibody_var2 with additional holes in front for M3 brass inserts for only mounting helicoid. Same placement.

Supports - Yes

## CHECKING THE DIMENSIONS

After printing the bottom body part (and before printing, in slicer) check the dimensions with reference on the next page. Minor and reasonable uncertainty in measurements is possible. About 0,2-0,4mm is absolutely fine (not in slicer of course).

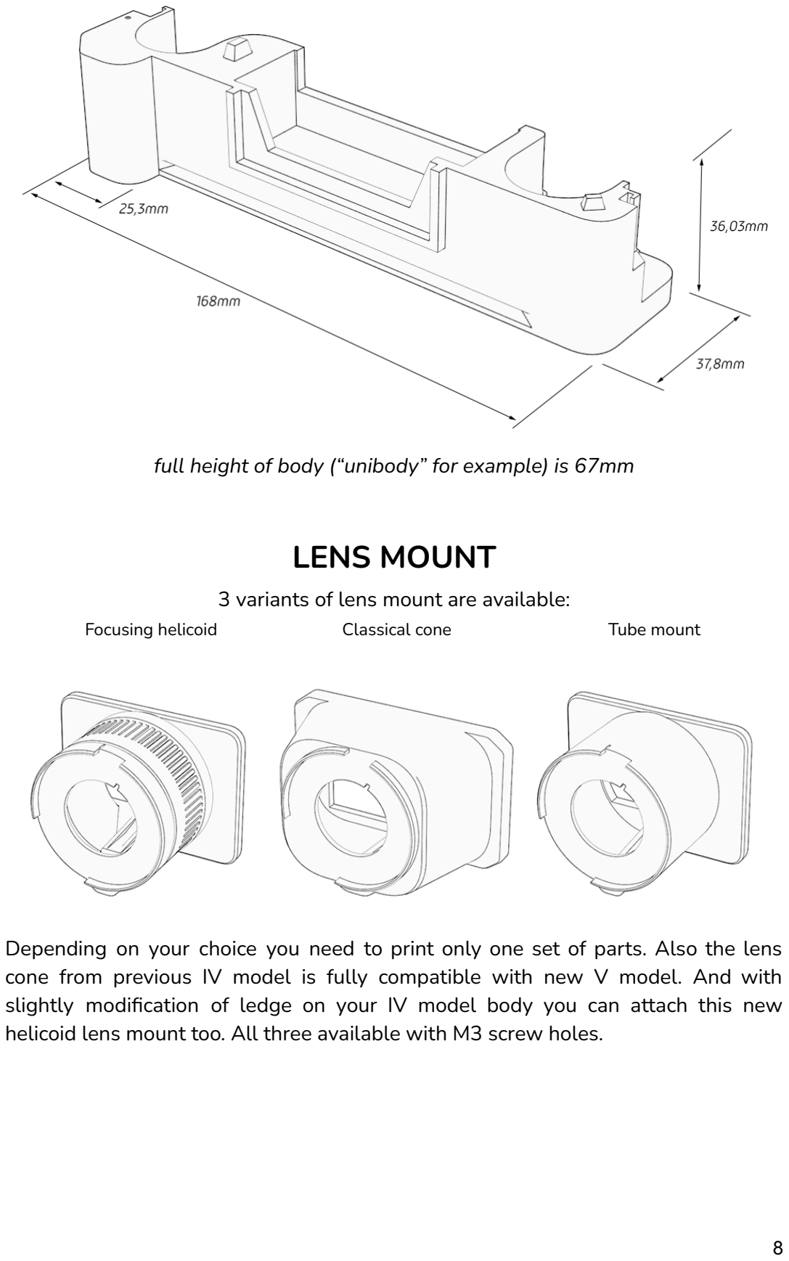
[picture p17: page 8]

full height of body (“unibody” for example) is 67mm

## LENS MOUNT

3 variants of lens mount are available:
Focusing helicoid | Classical cone | Tube mount

Depending on your choice you need to print only one set of parts. Also the lens cone from previous IV model is fully compatible with new V model. And with slightly modification of ledge on your IV model body you can attach this new helicoid lens mount too. All three available with M3 screw holes.

## HELICOID VERSION LENS MOUNT

HELICOID MOUNT VARIATION 1 Contain: Helicoid_MOUNT_ver1

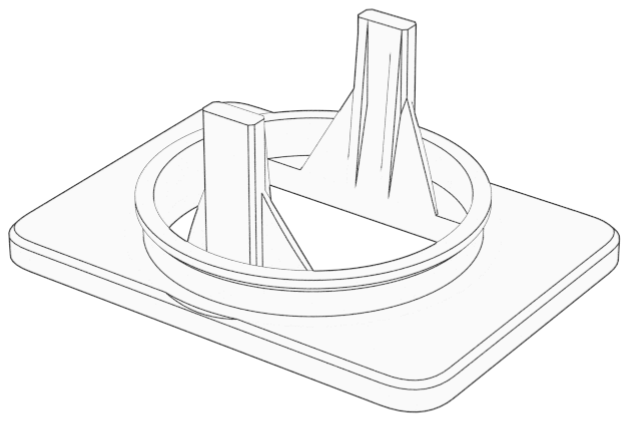
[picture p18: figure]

placement on printer bed

HELICOID MOUNT VARIATION 2 Contain: Helicoid_MOUNT_ver2

placement on printer bed
Helicoid mount version with four holes for attaching it to the body with four M3*10 screws.

HELICOID FOCUS RING VARIATION 1 Contain: Helicoid_FOCUS_ring_ribs

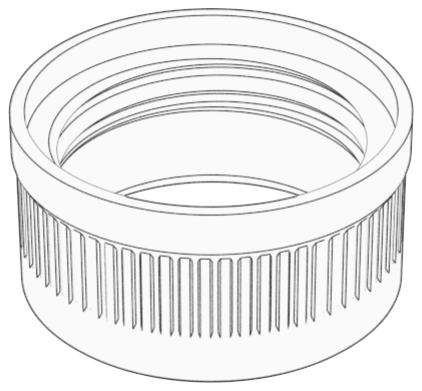
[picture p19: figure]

placement on printer bed

HELICOID FOCUS RING VARIATION 2 Contain:
Helicoid_FOCUS_ring_NO_ribs

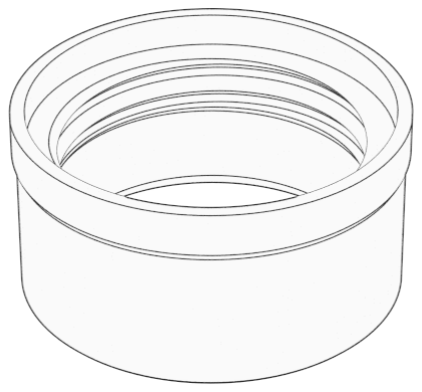
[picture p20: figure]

placement on printer bed
Same focusing ring just without ribs.

HELICOID INNER RING
Contain: Helicoid_INNER_ring

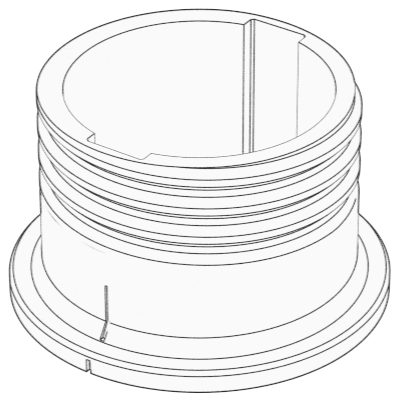
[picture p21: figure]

placement on printer bed

HELICOID FIXATOR RING
Contain: Helicoid_FIX_ring

placement on printer bed

HELICOID LENS BOARD
Contain: Helicoid_Lense_BOARD and Helicoid_Lense_BOARD_lower*

placement on printer bed
*lower version for focal length compensation. Start with normal one

## CLASSICAL CONE LENS MOUNT

CONE BASE
Contain: CONE_lens_classic_BASE also available with M3 holes

placement on printer bed

CONE LENS BOARD
Contain: CONE_lens_classic_BOARD

placement on printer bed

After quite huge investigation that my friends did, it was established that “Blue Dot” lenses do not share the same flange distance as regular 80mm lenses. I started receiving messages from different people, who had a copy of the Blue Dot lens, that they have difficulties with achieving the infinity focus. It was always the blue dot version. My friend Giuseppe found information about its unique characteristics online. After that i designed a short version of helicoid for @analog_astronaut and he confirmed that now he has infinity focus. Of course he made some stunning images as proof.

What does it mean to you? Well, if you you have blue dot lens, you have to print following set of parts:

### 1. Helicoid_INNER_ring_80mm_shorter-2mm.STL

2. Helicoid_FOCUS_ring_ribs_shorter-2mm.STL (or without ribs on your choice)
New files are included.

Huge thanks to Giuseppe who found that information and to the @analog_astronaut for boosting up this project in the media. You guys rocks!

## TUBE LENS MOUNT

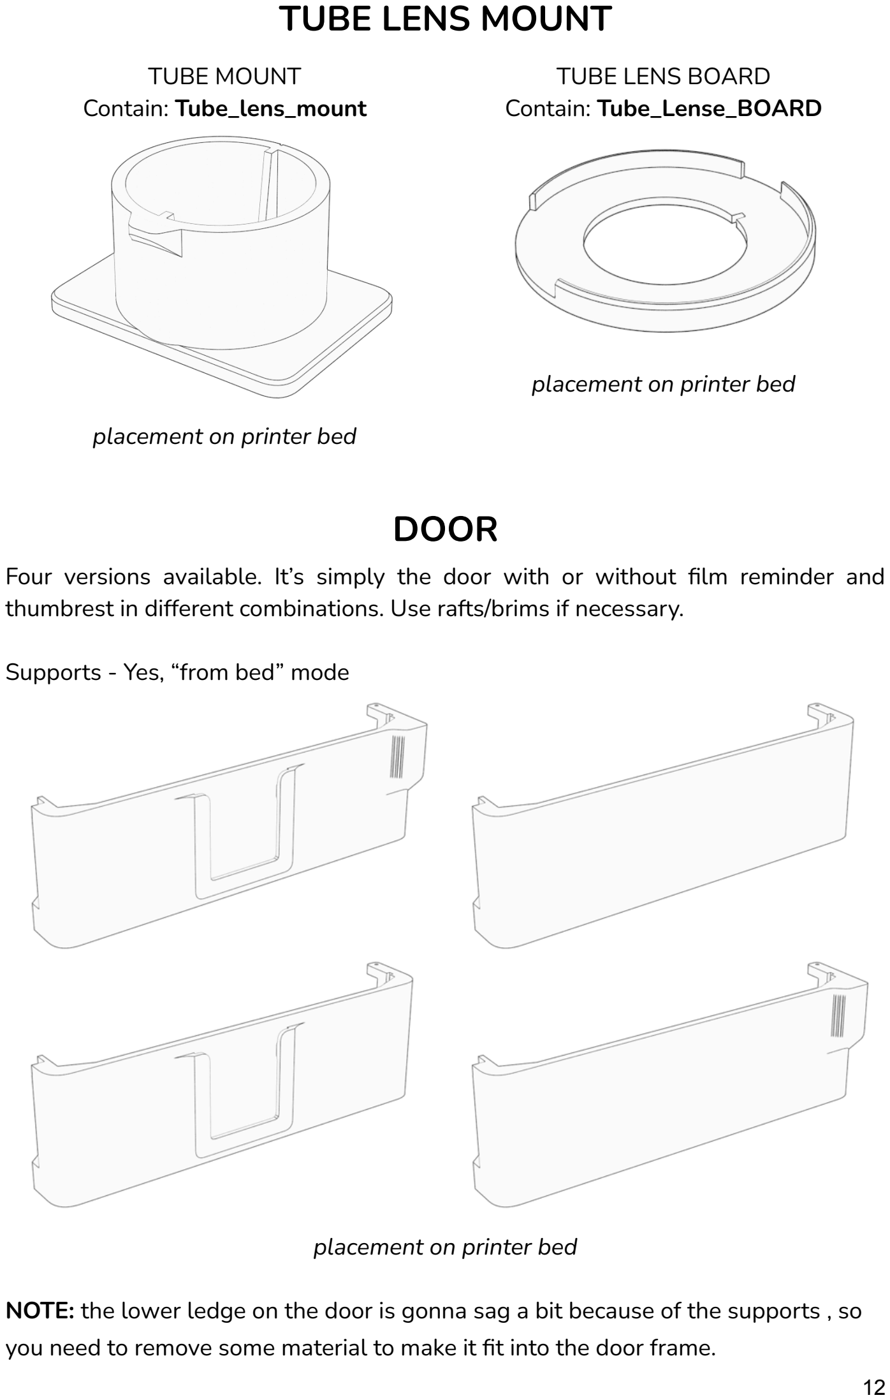
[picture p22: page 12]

TUBE MOUNT
Contain: Tube_lens_mount

placement on printer bed

TUBE LENS BOARD
Contain: Tube_Lense_BOARD

placement on printer bed

## DOOR

Four versions available. It’s simply the door with or without film reminder and thumbrest in different combinations. Use rafts/brims if necessary.

Supports - Yes, “from bed” mode

placement on printer bed

NOTE: the lower ledge on the door is gonna sag a bit because of the supports , so you need to remove some material to make it fit into the door frame.

It is essential to place the door this way on printer bed, since you need to provide strength in both horizontal axes. For example, if you are gonna place it on flat surface of the door, it should be rigid in vertical and one horizontal axis, but it could be too weak for holding the door closed.

## SMALL PARTS

General recommendation is to print heavy each loaded parts (such as rewind knob, taking spool shaft and latch) separately to achieve strong interlayer adhesion, overvise parts can be too weak. Other small parts can be printed in one set at twice the amount - as practice has shown, some elements can be damaged while fitting the parts to each other.

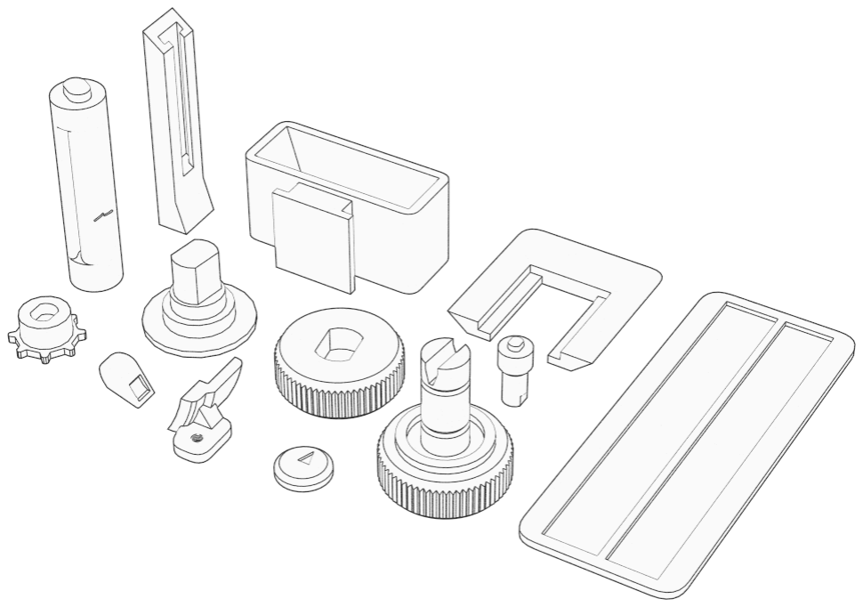
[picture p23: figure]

placement on printer bed

Winding/Rewinding knobs and viewfinder are available in two variations.
In some cases rafts/brims/mouse ears will be needed for better first layer adhesion of small parts.

## ASSEMBLY

## Checking the fitting of parts

Before you can permanently glue your fingers to freshly printed parts, let's check how they fit together. That's the step where you need your optional tools such as file or sandpaper, cutting knife etc.

In general - you should check the fitment of big parts first. Too loose - reprint. Too tight - shape it with tools. Rotating parts should not get stuck or dangle (the exception is the taking spool shaft. The seat-hole at the bottom of the body is made so that the shaft can go slightly deeper into it).

ATTENTION! The glue fumes are dangerous and will distract you from gluing as your eyes will water. Please wear safety glasses and a respirator!

## BODY

“Unibody” dudes can move to the next step. Two halves of the body probably have a gap between, and if it’s not wider than 0.4mm - you're good to go. Just need some sending and more pressure while you are gluing them, probably a good idea to use clamps. And of course you need to fill this gap with putty or solder it.

Critical is to make frame planes as parallel to each other as possible, since it will affect your focus plane. You can make it by placing both parts on a table, or other flat surface, or use film pressure plate as a guide by placing it on the orange film rails.

If you chose a version with holes for brass inserts, it’s time to insert them with soldering iron. Please be careful. Holes are for M3 brass inserts (diameter - 4,5mm; height - 6mm). Don’t pull your iron away, there is a hole on the bottom of the body for ¼” (diameter - 8mm; height - 8mm) brass insert, so you can use other tripods platforms.
NOTE: after installing brass inserts some excess plastic will be squeezed out. You need to remove it flash with the surface of camera body.

## LENS MOUNT

After gluing the body, you can check the fitting between it and lens mount, installing it in the ledge on the body. If necessary, grind some material off the lens mount part.

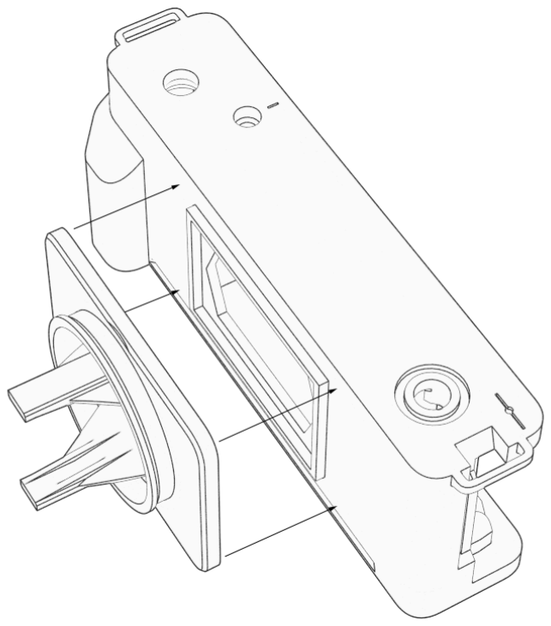
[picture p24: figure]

### 1. Once you are sure that everything is ok, glue the lens mount to the body using a

superglue or epoxy glue. Or temporary attach it with M3*10 screws. Take a look at the small box on the part (highlighted orange) that indicates the bottom side. Highlighted in orange - is the place you should apply glue (but not the small box of course 🙂).

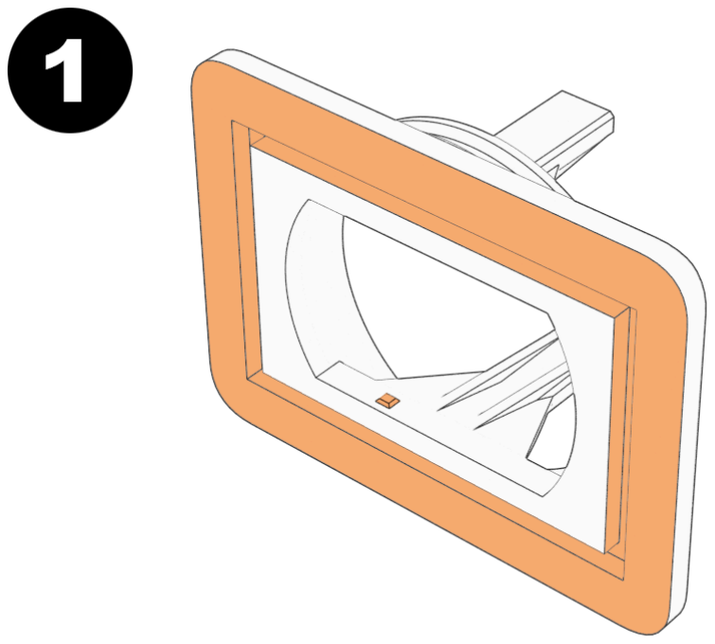
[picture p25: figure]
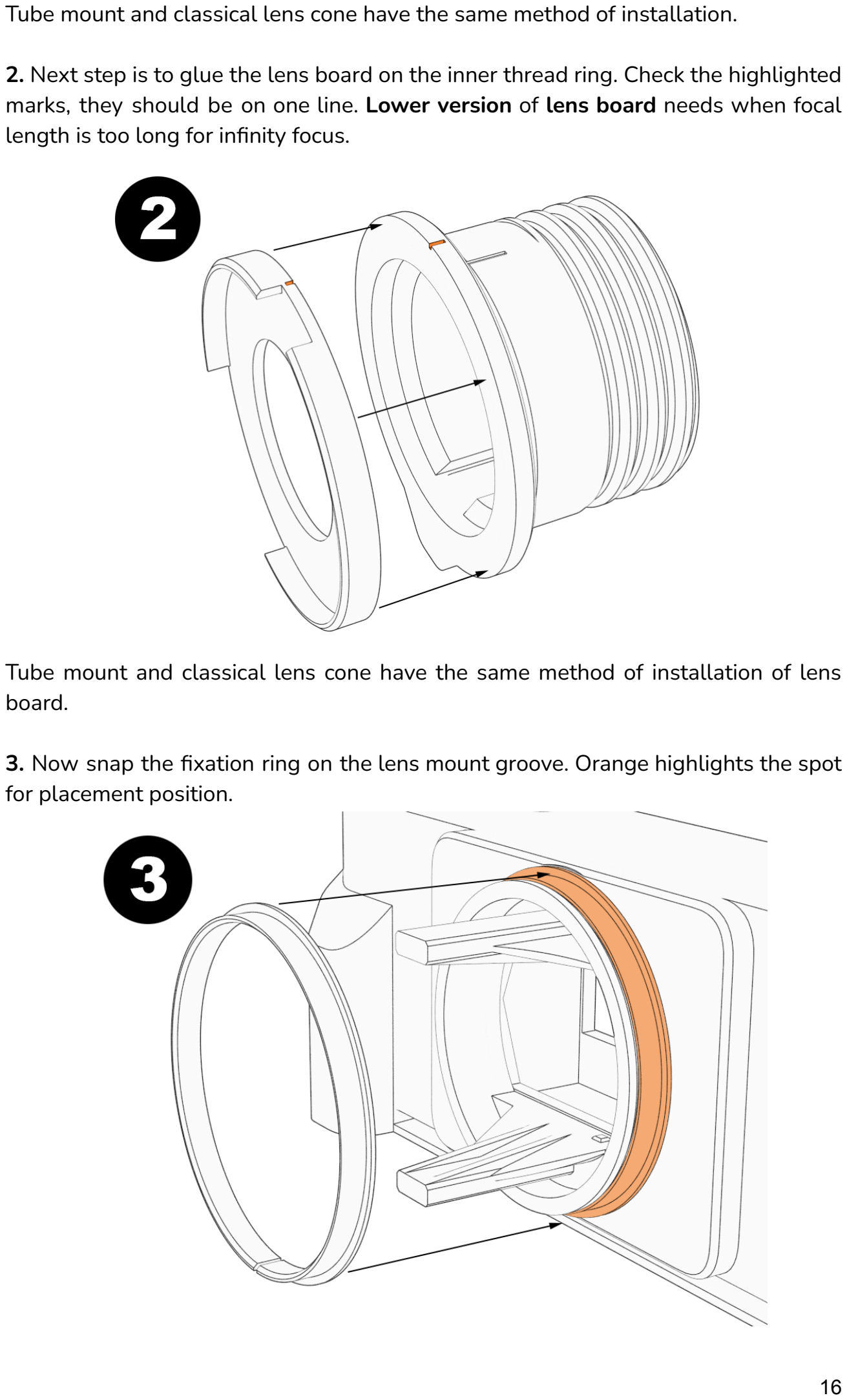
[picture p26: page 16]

Tube mount and classical lens cone have the same method of installation.

### 2. Next step is to glue the lens board on the inner thread ring. Check the highlighted

marks, they should be on one line. Lower version of lens board needs when focal length is too long for infinity focus.

Tube mount and classical lens cone have the same method of installation of lens board.

### 3. Now snap the fixation ring on the lens mount groove. Orange highlights the spot

for placement position.

4. Place glue on the surface of the fixation ring that we just snapped in place. ATTENTION! Be really careful not to glue it to the lens mount groove. Then place the focusing ring on that fixation ring and press it mildly for a few seconds. Check the rotation. It should rotate freely without dangling and without the possibility of falling out of the groove.

### 5. Check the inner thread with lens board operation. Place it inside the focusing ring

so that the slides of the mount fits into the grooves of the inner thread ring. Then simply start rotating the focusing ring clockwise. It should screw in all the way.

If it takes too much force to screw it down, probably you need to print smaller version of the inner thread, or sand surface a bit. If you are planning to grease it, don’t forget to use thick grease instead of liquid.

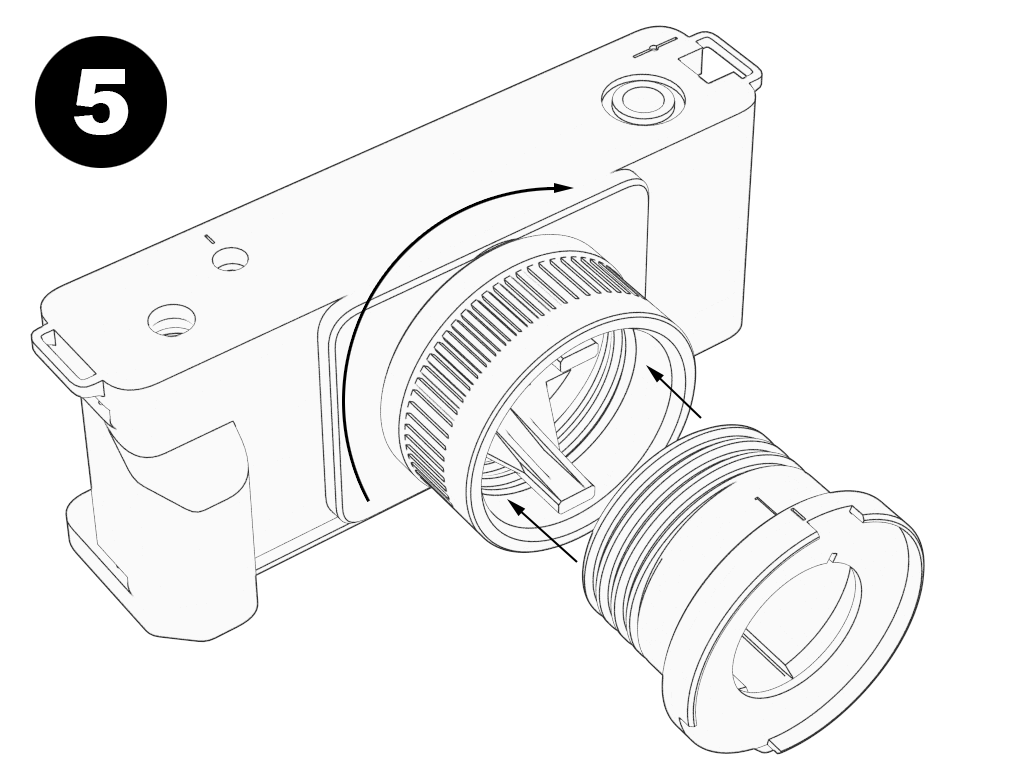
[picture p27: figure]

After checking, you should unscrew it back, as it may interfere with further assembly.

### 6. Place the spool base part on the top side of the body. Then apply glue on the

highlighted part of the spool shaft, and using tweezers, place it inside of the camera body at a slight angle, push it down and forward, until it stops. Then glue together two parts. Check the rotation. This part should have free space for moving down and up for now. You should glue the winding knob at top after you finish body and paint works.

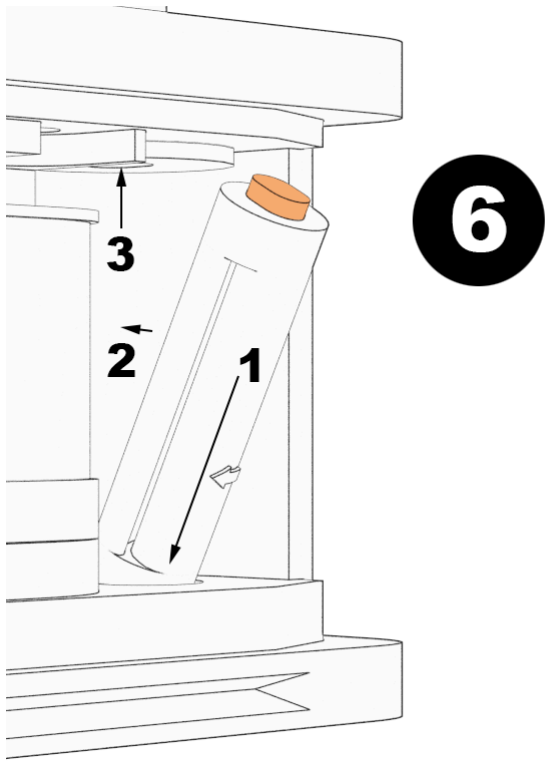
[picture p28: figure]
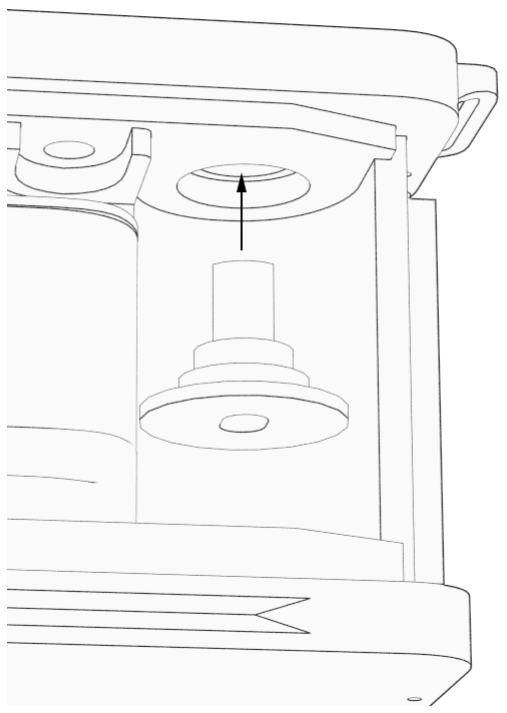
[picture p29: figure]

### 7. Place the sprockets gear into the slot, then apply glue to the sprocket shaft and

attach it to gear through the shaft hole from up side.

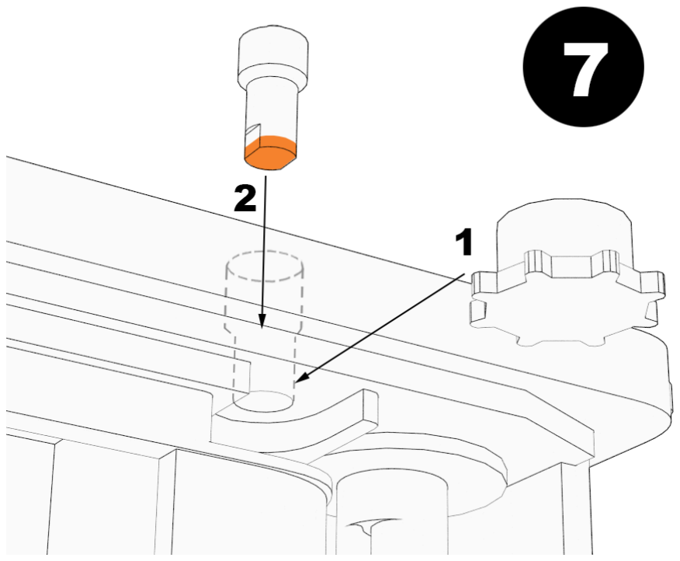
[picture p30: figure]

After you finish a paint job, you should glue the frame counter cap to the sprockets shaft. Of course don’t forget to mask these small parts on top, otherwise you will glue them to the body with paint (or simply place it on after painting).

### 8. Now you need to bend the wire into a V-shaped spring. I recommend doing this

with a small coil so that it is stiff enough to fix the rewind knob. Take the measurements and cut it.

### 9. After, place it inside of the slot. There are three bumps where it should be

installed.

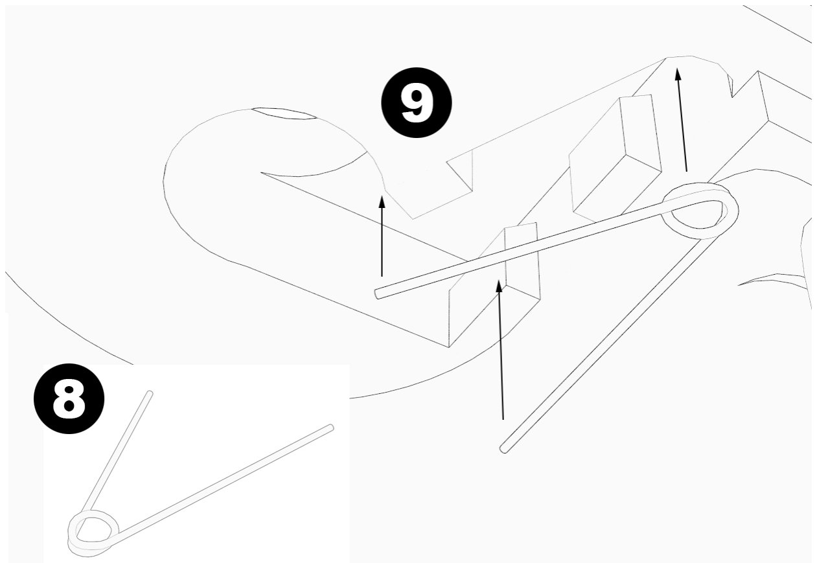
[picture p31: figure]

Next, insert the rewind knob and make sure it locks in the closed and open positions. After checking, better to pull it out, as it may interfere with further assembly and painting. These steps are tricky, be patient, I believe in You.

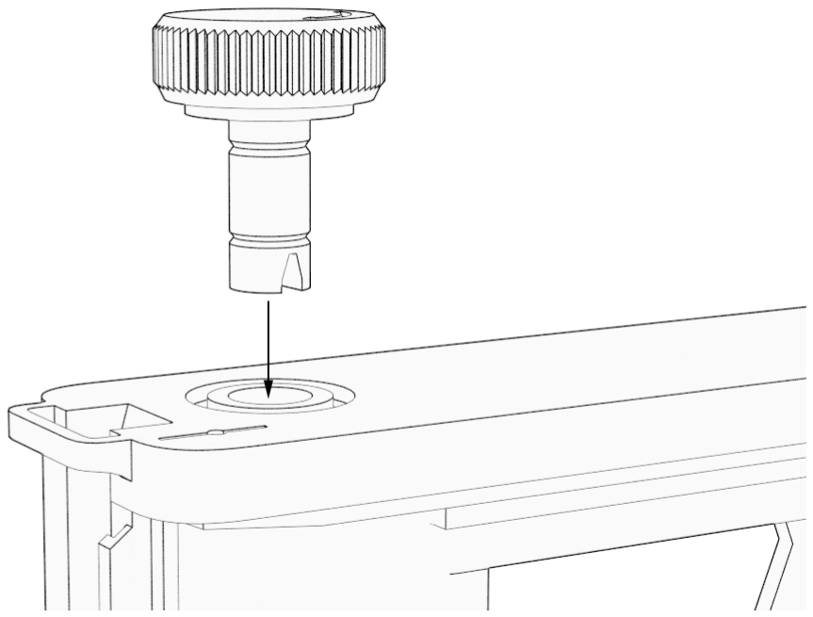
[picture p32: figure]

## DOOR

10. Next, we will install the door with the film pressure plate. First place the door. Check its fit. Door can be a bit tight, that’s ok. After you are sure that the door opens and closes, set it in the closed position and hinge it with the wire putting it through the hole in the body below to secure the door. The wire should fit tightly and not be able to fall out during operation. For reliability, this hole can be soldered or filled with putty.

Length of wire is about 63mm

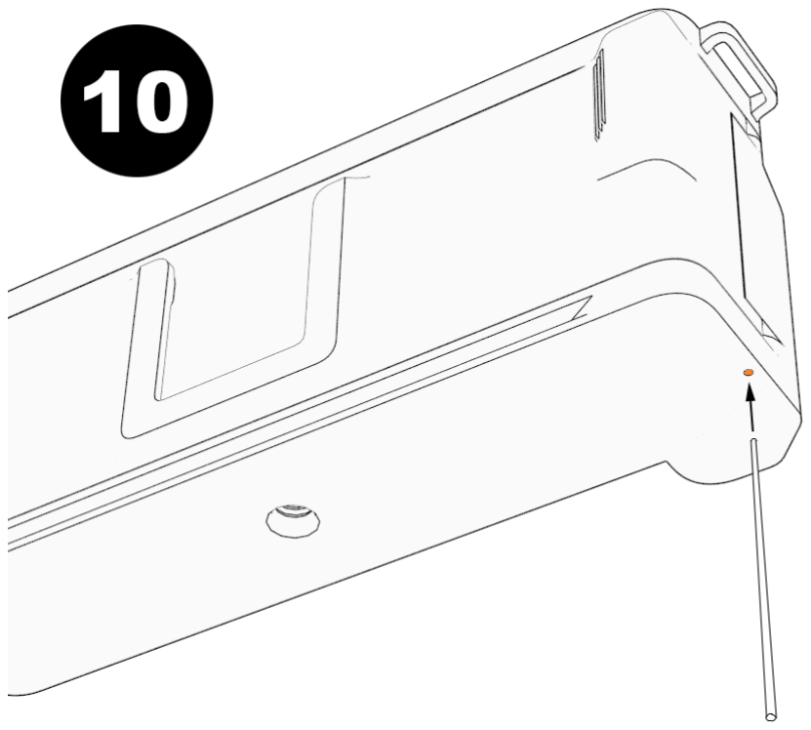
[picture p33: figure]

Next, I strongly recommend covering the flat side of the pressure plate with either black velvet self-adhesive paper (flocked paper) or matte black vinyl to prevent scratches on film. Do not use gray or even more light material unless you want strong halations and a hazy effect on your images. Templates are on the last page.

### 11. Then, take and cut two strips of foam, apply double-sided tape to them on both

sides. Then attach these strips to the plate between the ribs. There is no need to make the foam too thick. 4-5mm is quite enough.

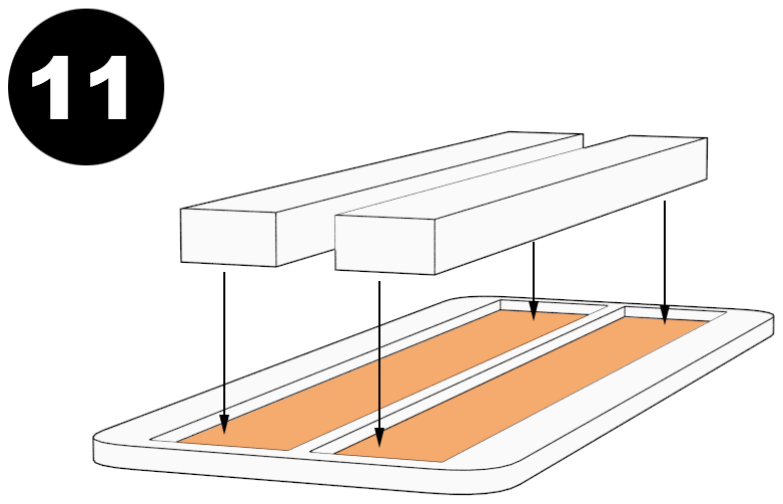
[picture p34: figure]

Then place the film pressure plate flat on the inside of the body, in place where an actual film is supposed to be, so that the plate does not touch anything inside and lies flat covering the frame window. Prepare double-sided tape and close the door completely.

After opening the door, the film plate should stain on it. Gently press it against the door a couple of times to make sure everything is ok. Take the latch and check how it fits into the lock place. Door should be flash with the surface of the camera body.

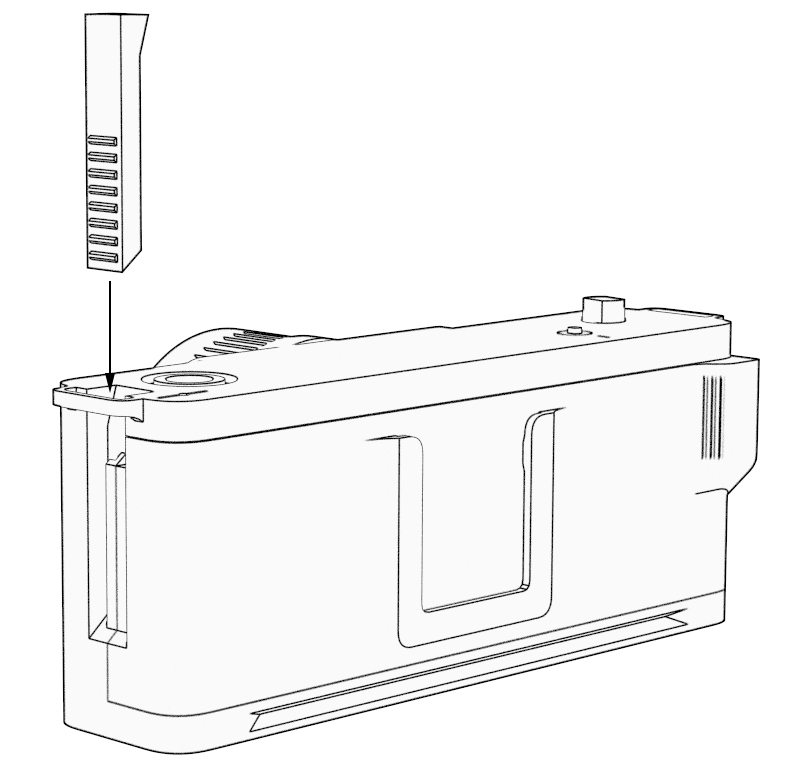
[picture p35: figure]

Finally attach the Mamiya lens to the inner thread ring using the original mount nut which was on the Mamiya TLR lens board.

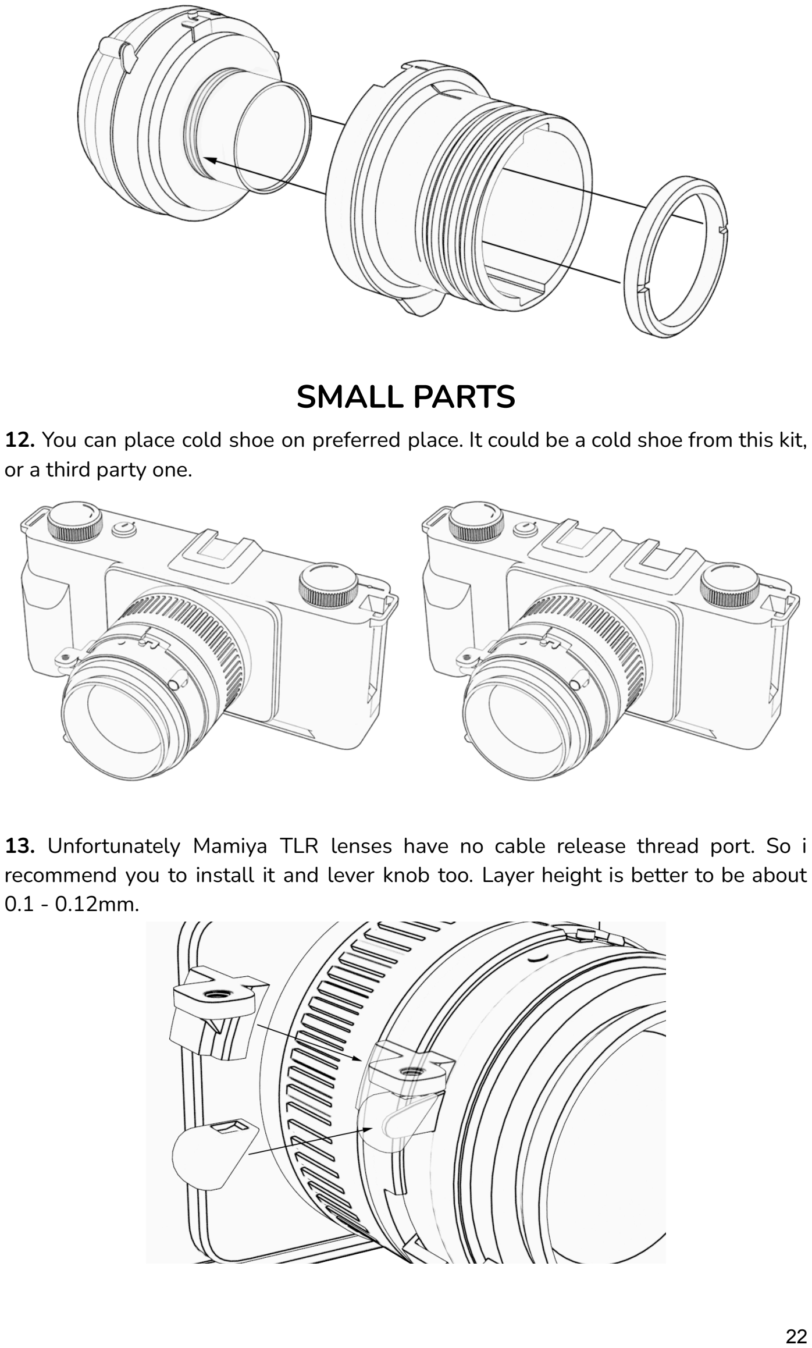
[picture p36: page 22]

## SMALL PARTS

12. You can place cold shoe on preferred place. It could be a cold shoe from this kit, or a third party one.

### 13. Unfortunately Mamiya TLR lenses have no cable release thread port. So i

recommend you to install it and lever knob too. Layer height is better to be about 0.1 - 0.12mm.

### 14. Also you can print lens hood, which is available in two variants. It is held on the

front lens element by friction. Better to check your lens diameter before printing the hood and scale the hood to it.

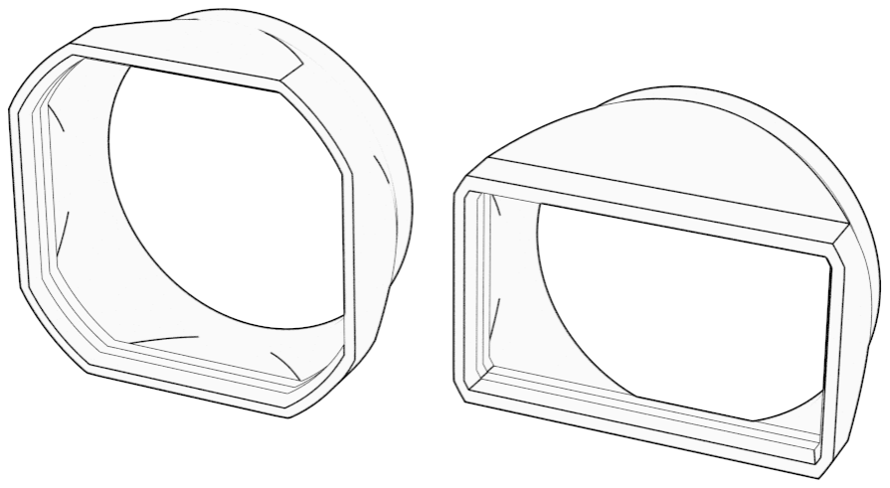
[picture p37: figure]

## FOCUSING

After all the necessary steps have been completed, you need to set the infinity mark on the focusing ring. To do so, you need some sort of ground glass. In my case I use 1mm thick glass for microscopes. It’s conveniently 75 by 25mm. I used special matting paste for glass to make it frosted on one side.

Basically you need to screw the helicoid all the way in - that should be infinity focus, which on Mamiya 80mm is about 31 meters (or nearly 102 feet).
Then you wrap around the focusing ring piece of paper and make the marks on it for your preferred distances. My calculations show me that one 300 degree turn provides focusing from infinity up to 2 meters. Yes, you can go further and mark macro distances, BUT be careful since the lens could fully unscrew and fall out.

Infinity focus you can check simply by focusing on something really far away from your house. It could be a mountain, tower, tall building, you name it.

For focusing on near distances you need to measure preferred segments, such as 20 meters, 15, 10, 5 and so on. Place something bright and contrast on that distance and check via ground glass its focus. Make marks. Then scan this paper to make print of your own focusing marks.

example of such strip of paper. length for 300 degree rotation is 170mm it is an example, not an accurate thing.

## USAGE

## First tests

Since you have already tested infinity focus and work of helicoid, the next test is advancing the film back and forward.
Better to have a 35mm roll of already exposed and developed film, or just really cheap or expired one, so that it wouldn't be a pity to ruin it. Simply try to imitate normal use of it.
If the film is wound with a characteristic crunching sound and sprockets holes are torn - It is probably because sprocket gears are too sharp and square. In my case it was exactly like that. Simply just shape it with a file to smooth shape. You can copy the shape from other film camera if you have one.

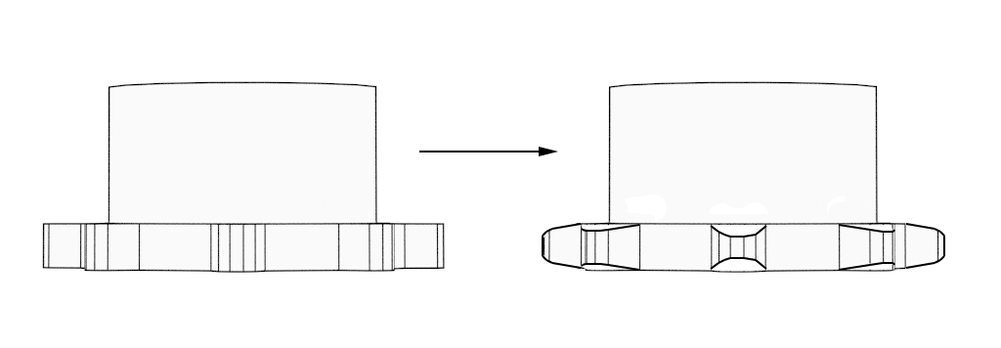
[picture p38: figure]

It is also possible that your film will slip through a few gear teeths. If this happens, glue a piece of foam on the door next to a place where film ends contact with sprocket gears. It will provide more tension between gears and film.

## Exploitation

Main issue of infidex, which I still couldn't overcome, it’s that you need to make 2 revelations of frame counter per 1 shot.

This problem can be easily fixed by replacing the 8-tooth sprocket gear with a larger 16-tooth gear. But it will increase the length of the camera body, which I really don't want.

## Viewfinder

Kit viewfinder is simple to use (which is available in two variations). just combine both frames into one silhouette, while viewing through, to get your correct framing. It is pretty accurate, but I recommend you keep some headroom on both upper and down sides of the frame. Or… just buy an optical 35mm viewfinder and mark new framing with ground glass, as I did.

## Exposures

From one standard roll of film with 36 exposures, you get 18 frames if you do everything carefully, And 19 frames if you load in the complete dark and use the first frame without rewinding. However, this is a bit heavy and there is a chance that the film will not lie flat. Make sure that starting mark on counter is on start position.

One frame takes two standar 3:2 frames, so it’s exactly 16 sprockets. Some respooled films can contain less than 36 exposures, keep that in mind.

## Scanning film

Not any lab can properly scan such long negs, so I scan it on my own. I use the Epson V850 pro. This is the easiest way, but not the best (see example below). More interesting way is DSLR scanning, when you stitch two frames. But it is time consuming.

Kodak Gold, infidex 176 III with Lomo T-22

## The end

I hope you will enjoy your new camera. Really want to see your images. You can send them to our joint gallery if you want: https://timetowaste.ru/joint
Peace.

## Special thanks

Huge thanks to “PaperBen” for testing my designs, advice and inspiration. It really helps a lot man. I owe you a beer.

Big thanks to Giuseppe Spataro also for testing my designs, advice, inspiration and solving the infinity mystery for blue dot lens.

Thanks to “ballanux” youtube channel for inspiration on the helicoid system for the new V infidex 176 model.

Thanks to Oscar Oweson (creator of Oxygen panoramic camera www.panomicron.com) for inspiration on some parts of the new V infidex 176 model.

Thanks to “GLOwl” (creator of printable lens cap www.thingiverse.com/thing:3241700) for inspiration on creating own version.

Thanks to the @analog_astronaut for boosting up this project in the media.

## Templates

Templates for flocking paper

## Depth of field table for Mamiya 80mm TLR

Aperture | Distance (metric)
inf. | 9m | 4,5m | 3m | 2m
2.8 | 32m - inf. | 7m - 12m | 4m - 5,5m | 2,8m - 3,4m | 2m - 2,2m
4 | 22m - inf. | 6,5m - 15m | 3,8m - 5,7m | 2,6m - 3,5m | 1,9m - 2,3m
5.6 | 15m - inf. | 6m - 21m | 3,5m - 6,3m | 2,5m - 3,7m | 1,8m - 2,4m
8 | 10m - inf. | 5m - 51m | 3,2m - 7,6m | 2,4m - 4m | 1,8m - 2,6m
11 | 8m - inf. | 4,3m - inf. | 3m - 10m | 2,2m - 4,7m | 1,7m - 2,8m
16 | 5,5m - inf. | 3,5m - inf. | 2,5m - 23m | 2m - 6,4m | 1,5m - 3,2m
22 | 4m - inf. | 2,8m - inf. | 2m - inf. | 1,8m - 10m | 1,4m - 4m
32 | 2,7m - inf. | 2m - inf. | 1,8m - inf. | 1,5m - inf. | 1,2m - 7,3m

Green zone - the sharpest aperture settings
Orange and red zone - diffraction zone

Interesting thing is that the manufacturing chart goes only up to 9 meters (30 feets) and then up to infinity. On the original chart it starts from 1 foot but since I use this camera only from 2 meters this chart starts from 7 feet.

Why is there no imperial system table? Because it makes me sick 😅
But if you can help me refresh the original table with feet it will be really great!

Original table:

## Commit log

2026-06-08 Initial mirror: Infidex 176 V documentation and repo structure
    Community preservation of Denis Aminev's open-source panoramic 35mm film
    camera project (timetowaste.ru shutting down March 2027). Includes English
    documentation reorganized from the original PDF manual and build video,
    Git LFS config for binary assets, and folder stubs for STL/FBX/MODS.
    https://claude.ai/code/session_01HBGJMgDwop9WpVHWyqmpA7
2026-06-08 Add all design files, organized repo structure, and download package
    - 57 STL print files organized into Body/, Lens mount/, Small parts/
    - 61 FBX mesh exports including Kodak cone and metal part references
    - 14 community MOD files (STL + FBX) for body/door/mount variants
    - Original PDF manual and 3ds Max source file (.max)
    - Author's complete release archive as downloads/Infidex_176_V_complete.zip
    - Updated README with download section, full file tree, and file sources
    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
    [BODY_UNIBODY.stl, BODY_UNIBODY_ver2.stl, BODY_bottom.stl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]
2026-06-08 Add Printables upload guide with listing text and field recommendations
    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
2026-06-08 Replace Chinese text with English in Printables listing guide
    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
2026-06-08 Add Printables listing guide for GX617-style lens cage accessory
    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
2026-06-08 Update lens cage listing to V2 with integrated hood and strap balance details
    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
2026-06-08 Remove Printables listing guides (kept locally, not needed in repo)
    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
